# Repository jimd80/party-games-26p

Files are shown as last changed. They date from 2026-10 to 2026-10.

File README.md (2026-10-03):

# 26 Player party game setup

Up to 26 senders
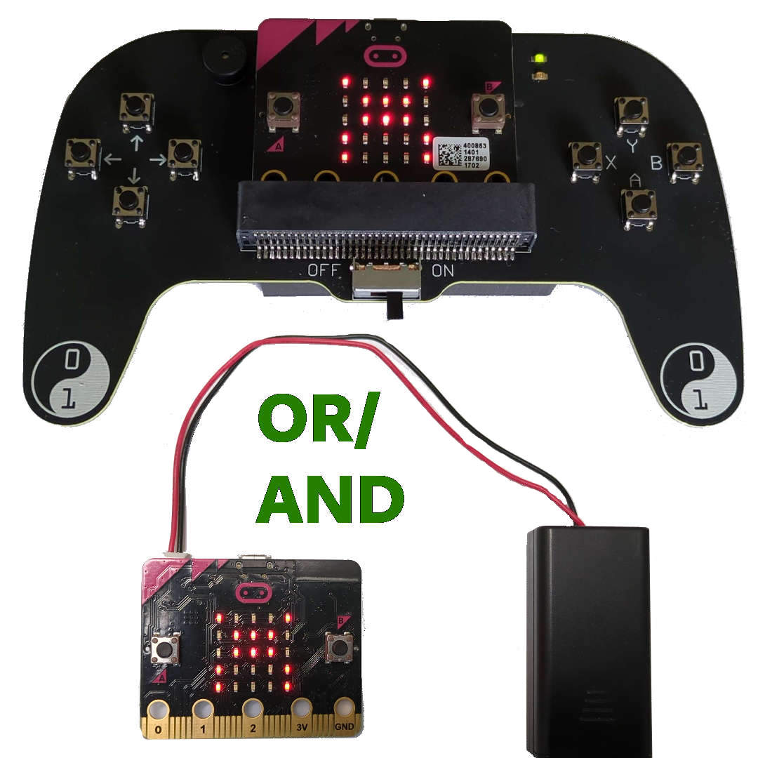
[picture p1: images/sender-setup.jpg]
Sender setup

go to a single receiver
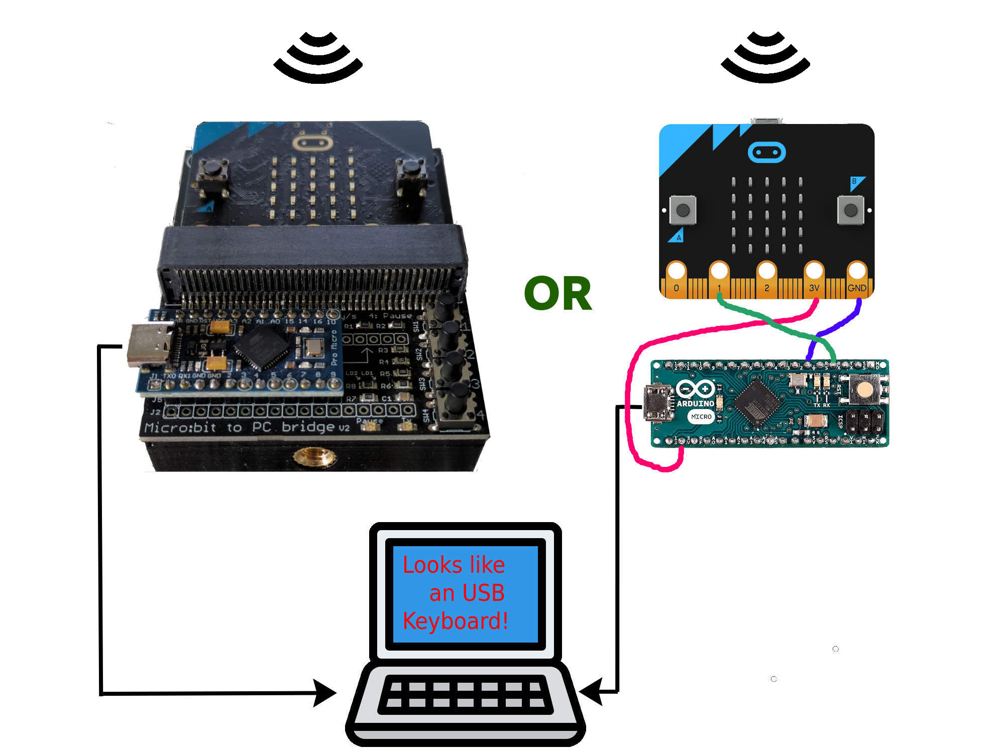
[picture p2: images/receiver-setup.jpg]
Receiver setup


Sending keys A–Z for 26 players.

## The concept
Up to 26 micro:bits act as wireless game controllers. One micro:bit is used as a receiver. Each time a player presses a button, the receiver micro:bit sends a character (A–Z) to the serial port of the Arduino. The Arduino acts as a virtual keyboard for the PC and passes the player's keystrokes as a–z keypresses (player 1 = a, player 2 = b, ..., player 26 = z).

This has some benefits:
- No drivers required; works on any PC, Mac, Chromebook, tablet, etc.
- Games can be developed without the hardware; just use the keyboard `a`–`z` keys to test!
- Easy to develop!

## Setup
Of course you'll need games to play. Check out [games-examples](games-examples/README.md) for a guide on how to write games or directly try the examples.

### The sender
For the sender you have 2 options:
- A micro:bit with a battery box
- Or build the [game controller](https://github.com/jimd80/pxt-coderdojo-controller)

Load [microbit-GameController-v25.12.hex](sender-microbit-src/microbit-GameController-v25.12.hex) from [sender-microbit-src](sender-microbit-src/README.md) into each sender micro:bit using [MakeCode](https://makecode.microbit.org/#editor) or drag it to the `MICROBIT` folder in your file manager.

### The receiver
Get an Arduino Micro, or the Pro Micro clone. Flash [receiver-arduino-v25.7.hex](receiver-arduino-src/release/receiver-arduino-v25.7.hex) from [receiver-arduino-src](receiver-arduino-src/README.md) into the Arduino.

Get a dedicated micro:bit to use as a receiver. Flash [microbit-GameReceiver-v26.3.hex](receiver-microbit-src/microbit-GameReceiver-v26.3.hex) from [receiver-microbit-src](receiver-microbit-src/README.md) into the receiver micro:bit.

Connect the Arduino and micro:bit with 3 wires, as described in [receiver-arduino-src](receiver-arduino-src/README.md).

Alternatively, build the receiver PCB as described in [receiver-pcb](receiver-pcb/README.md).

## How to play
There are plenty of modes to use this setup. We'll go from easy to advanced.

### Quick 26 player
The easiest and fastest setup to play a multiplayer game.

**Senders**: Players just need to turn on their micro:bit. A `?` will appear shortly and a letter is auto-assigned. Button A is the action key to play.

**Receiver**: Plug in the receiver. `26` will appear briefly on the screen. Press button B until `A` (**A**uto-assign) appears and press button A to confirm.

### Personalized 26 player
The controllers are personalized. Give each player a secret code they need to enter into their micro:bit in order for their predefined letter to appear. If managed well, games can keep a preset list of the players' names to show in-game names of the players. The list of "secret codes" can be found in [sender-microbit-src](sender-microbit-src/README.md).

**Senders**: After a player has powered up their micro:bit, a `?` will appear. Now they need to input their code by pressing A and B alternately. For example, if a code is 4567, then A needs to be pressed 4 times, B 5 times, A 6 times, and B 7 times. After this, their assigned letter will appear on the screen.

**Receiver**: Just plug in the receiver; the default mode will just work.

### Programming challenge 26 player
For an extended experience, you can let the players program their micro:bit by themselves with MakeCode blocks.

**Senders**: Let the players create the code as shown in [sender-microbit-src](sender-microbit-src/README.md) (replacing 9999 with their personal code).

**Receiver**: Just plug in the receiver; the default mode will just work.

### 8 button mode 26 player
Games can be advanced to enable all 8 buttons from each player's controller. In this mode, the game not only needs to look at the letter that was pressed, but also at the preceding number, which indicates the button. Each button press from a player is sent as 2 keystrokes, like `5c` = button 5 for player c. More information can be found in [games-examples](games-examples/README.md).

This mode only works if you have both the [game controller](https://github.com/jimd80/pxt-coderdojo-controller) and [receiver PCB](receiver-pcb/README.md).

**Senders**: Same setup as **Quick 26 player** or **Personalized 26 player**.

**Receiver**: Plug in the receiver. Long-press button 4 on the receiver PCB. The green LED will turn on to indicate multi-button mode.

### 8 button mode 4 player
Another way of enabling all 8 buttons per player is limiting the maximum player count to 4. In this way, all 32 keys (8 x 4) can be mapped to a single key on the keyboard, making game programming much easier than the 8-button 26-player mode above.

This mode only works if you have the [game controller](https://github.com/jimd80/pxt-coderdojo-controller).

**Senders**: Power on the micro:bit so `?` appears. Hold A+B until I, II, III, or IIII shows up on the screen to choose player 1–4.

**Receiver**: Plug in the receiver. Press button A until `4` shows up on the screen. The first row of 4 LEDs shows the online status of controllers 1–4.

### Micro:bit project mode
This mode is not to be used with the receiver, but with another custom-programmed micro:bit controlling their own hardware project. More info in the [Remote controlled car exercise](https://drive.google.com/file/d/1tmhRcf0qA-TUM9EA2VIr5EyiVHkkNPFD/view?usp=sharing) (in Dutch).

**Sender**: Power on the micro:bit so `?` appears. Hold A+B until 1, 2, 3, 4, 5, 6, 7, or 8 appears.

**Receiver**: This is a custom program controlling hardware with the game controller.

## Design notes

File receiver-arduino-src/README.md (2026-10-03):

# Micro:bit to PC interface
This project will allow you to connect a micro:bit to an Arduino Micro (or a Pro Micro clone) and connect the Arduino to a computer via USB. The computer will recognize the Arduino as a native keyboard. No drivers required!

The Arduino will translate serial data from the micro:bit into USB KeyDown/KeyUp events.

## Arduino build instructions
The project can be built using VS Code with the PlatformIO add-on. Alternatively, `src/main.cpp` can be renamed to `.ino` if you are using the Arduino IDE. You will need to add the external library `arduino-libraries/Keyboard` manually.

You can tweak the constants `PLAYER_DELAY_MS`, `KEYPRESS_MIN_TIME_MS`, `KEYPRESS_MAX_TIME_MS`, and `MAX_KEYS_SAME_TIME`, but it is strongly advised to leave them as-is. These values were carefully chosen to meet most types of games (either high-volume clicker games or time-accurate "shooting" games).

Keep in mind that 26 controllers will generate a lot of keystrokes! The software is designed to handle a throughput of 26 controllers, each clicking 10 times/second, which is about the human limit of pressing a micro:bit pushbutton. The USB protocol also has a limit of 6 keyboard keys pressed at the same time. Therefore, the minimum time between a KeyDown and KeyUp event is set to 20 ms. This allows a total throughput of 300 keystrokes per second, which is about 11.5 clicks per second per controller.

The time before the same key can be sent again is set to 50 ms. This prevents cheating and buffer backlog floods. To protect even more from cheating, when the same key is received within 50 ms, the wait time will restart. This prevents a cheater from sending on a 30 ms interval, which would still result in a 60 ms interval. That is still faster than the human limit.

The keyboard layout is set to Belgium or France (AZERTY). If you use another keyboard layout, please change `KB_LAYOUT`.

## Flashing
No need to compile by yourself if you're okay with the default settings (like AZERTY and key press delays).

Use Arduino IDE or VS Code with PlatformIO to directly flash the hex file you can find in the `release` folder.

## Use without PCB

3 Wires are needed to connect the micro:bit to an Arduino Micro:

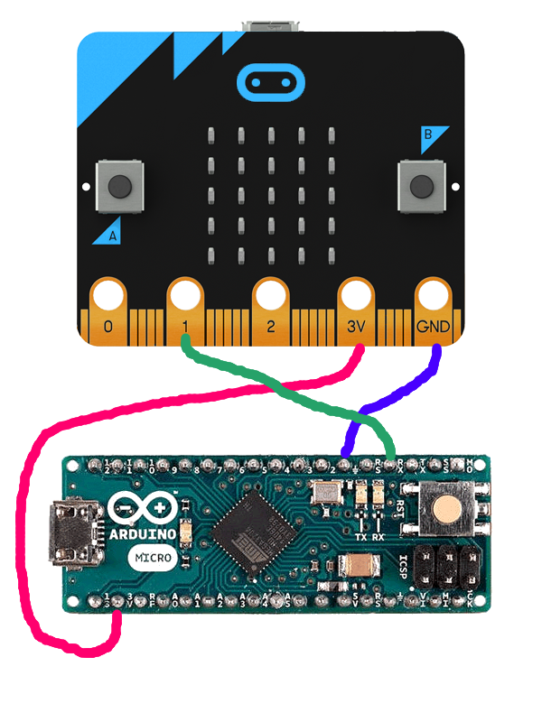
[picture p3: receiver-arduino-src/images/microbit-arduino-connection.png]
Arduino connection


Alternatively, for a Pro Micro the wiring is different:

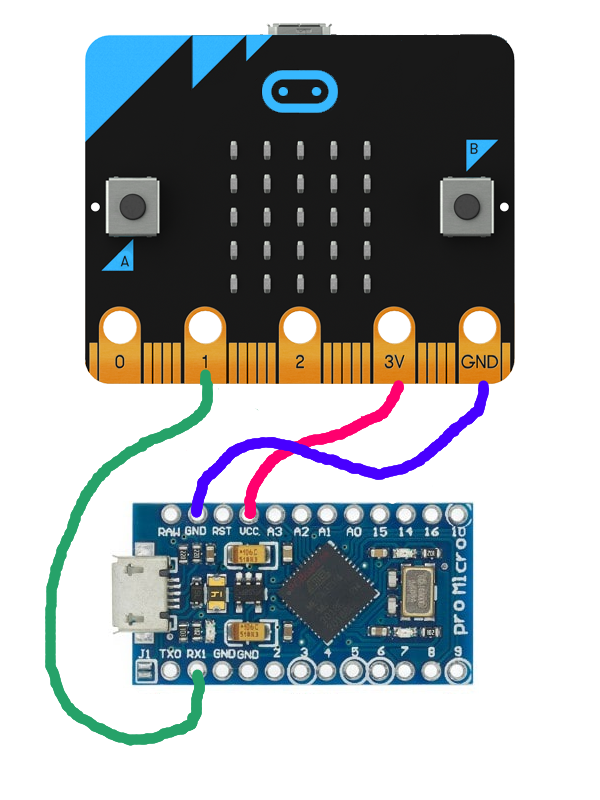
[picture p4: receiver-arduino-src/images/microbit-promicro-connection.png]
Pro Micro connection


## Extra features when using the PCB

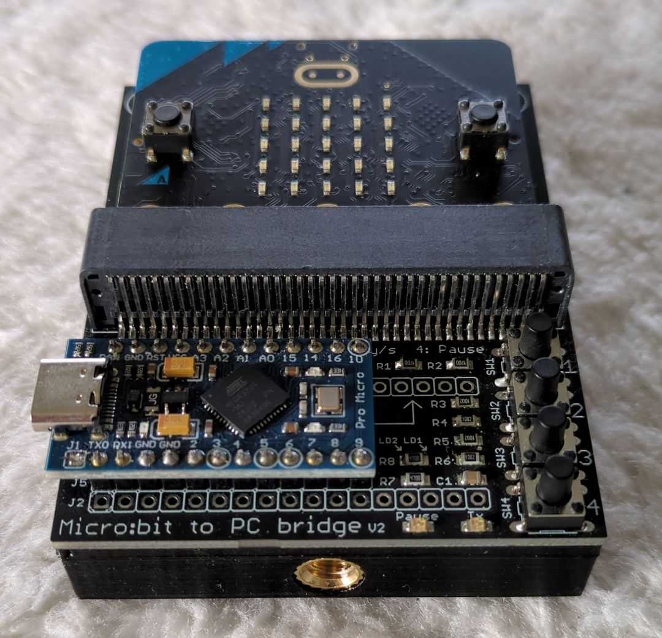
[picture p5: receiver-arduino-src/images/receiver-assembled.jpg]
Receiver


When using the software with our custom PCB, extra features become available:

- **Button 1 short press**: sends a keypress for the letter `a` to the computer. It is used to test if the keyboard is recognized by the computer.
- **Button 1 long press**: switches between AZERTY and QWERTY mode. If the above test sends a `q` to the computer instead of an `a`, switch modes.
- **Button 2 press**: rapidly sends all `a` to `z` keypresses with 5 milliseconds in between (26 keys in 130 ms total).
- **Button 3 press**: rapidly sends all `a` to `z` keypresses 10 times with 3 milliseconds in between (260 keys in 780 ms total).
- **Button 4 short press**: toggles mute mode. The red LED will be on to show that no keypresses are currently passed through.
- **Button 4 long press**: toggles between 1-button and 8-button mode. In 8-button mode, every player can use all 8 buttons on the game controller. Letters are prefixed by numbers to indicate which button is pressed.

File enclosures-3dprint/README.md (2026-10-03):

## Micro:bit, cable, and battery box holder

Print `Microbit case.stl` or choose a custom number of rows / columns by editing `Microbit case.scad` for compact storage.

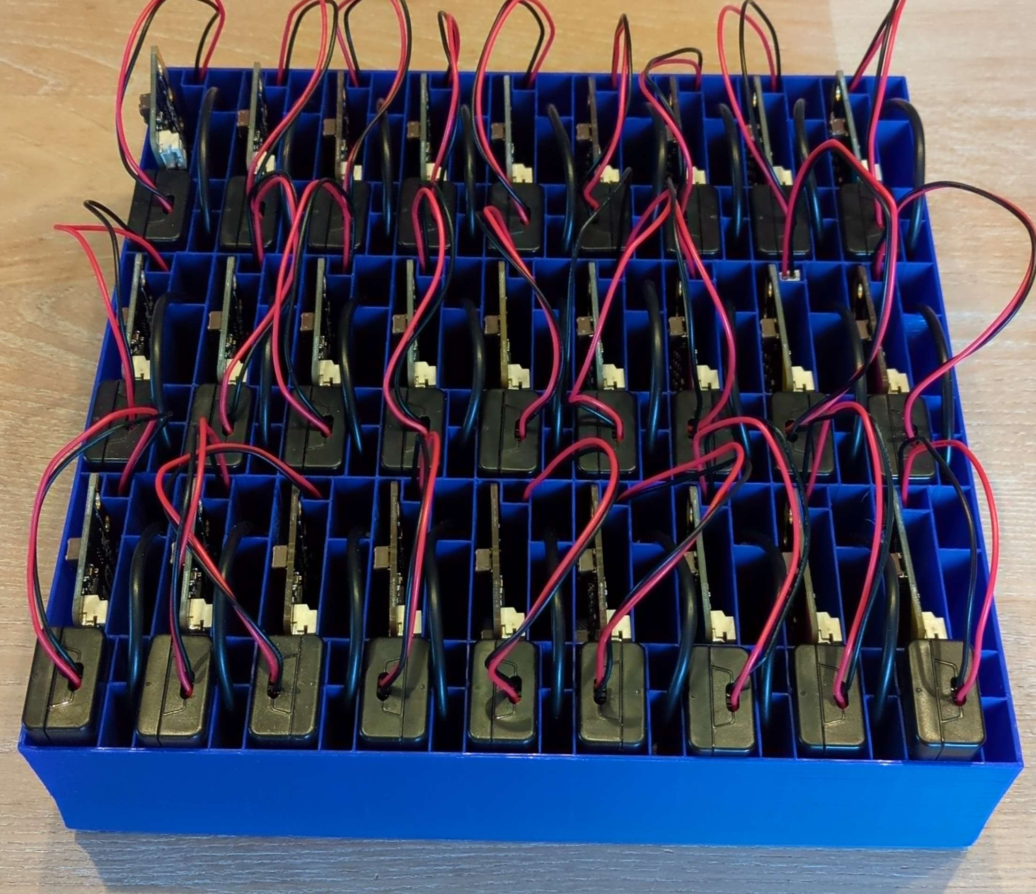
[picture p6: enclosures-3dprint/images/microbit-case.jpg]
Microbit case


## Game controller box

Controller box STL files are available to print a storage case for the game controllers. You can adjust the `Controler box.scad` file for any number of controllers.

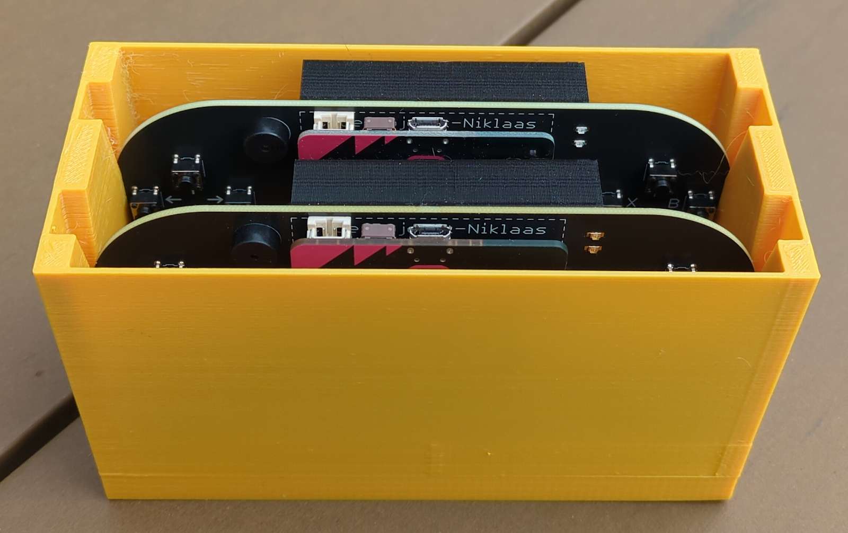
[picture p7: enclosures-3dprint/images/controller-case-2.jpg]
Controller case


Combine several holders so they will fit in a handy toolbox.

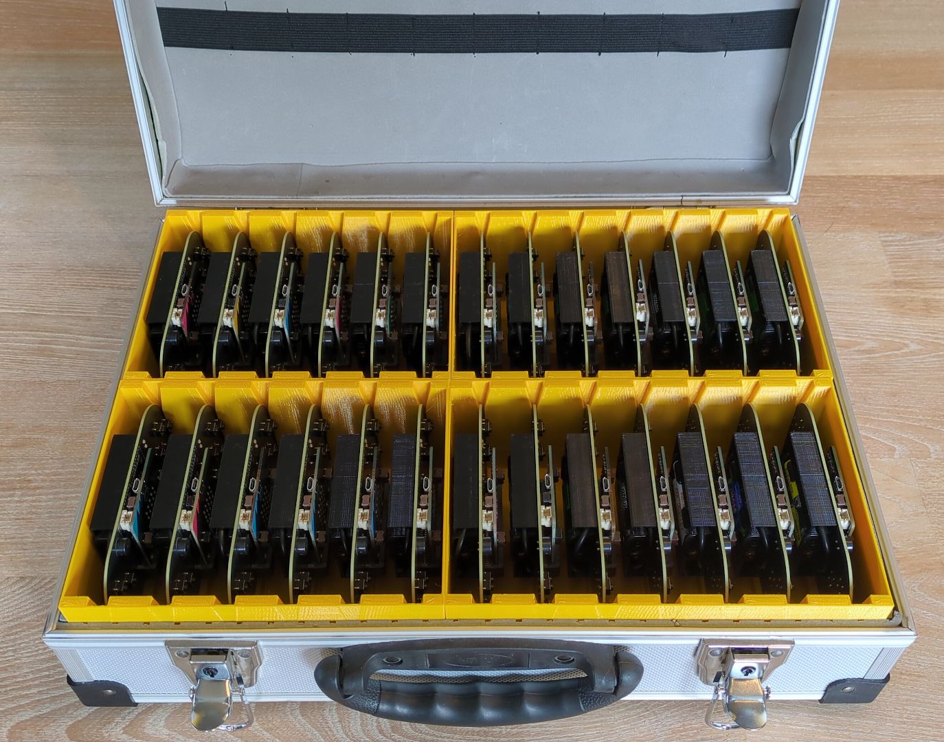
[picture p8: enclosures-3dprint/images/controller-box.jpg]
Controller box


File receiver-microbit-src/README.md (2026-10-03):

## Micro:bit 26p games receiver

This program works together with the Arduino. The micro:bit receives radio signals from the sender and sends the pressed key codes over a serial port to the Arduino, which then translates this into USB keyboard events.

Flash [microbit-GameReceiver-v26.3.hex](microbit-GameReceiver-v26.3.hex) into the micro:bit (which is connected to the Arduino) with [MakeCode](https://makecode.microbit.org/#editor) or drag it to the `MICROBIT` folder in your file manager.

## Button and LED usage

Button A toggles the mode between 26-player mode <-> Pause <-> 4-player mode.
Button B toggles through options (depending on the current mode). Press A to confirm the option.

### Modes (select with button A):
- **26-player mode**: Sends keys `a`–`z` to the computer. When a player keeps pressing their button, the key is repeated at a 300 ms interval. The 25 LEDs on the micro:bit show the online status of the a–y players.
- **4-player mode**: Sends keys from 4 controllers according to a specific mapping (see below). The LEDs on the micro:bit show a `4`, and the first 4 LEDs (top row) show the online status of the 4 controllers.
- **Pause mode**: Shows `||` on the LED screen. Keys are not sent to the computer. The option menu (Button B) has several test/debug options.

### Options (select with button B):
Not all options are available for each mode!
- **R**: Recover the player letter when a controller is turned off and on again so the player does not have to enter their code again.
- **A**: Auto-assign A–Z to controllers after power-up. Skip player numbers that were previously configured on other controllers. Also recover on power loss.
- **X**: Letter assignment A–Z is done by pressing the X button on the game controller. This allows setting a certain player order.
- **N**: Controllers do not remember their player letter and are not auto-assigned.
- **T**: Request 50 x 100 ms button A presses from 26p-configured controllers.
- **V**: Show version.
- **R**: Reset.
- **T**: Request all controllers in startup mode (showing a `?`) to send simulated button presses.
- **D**: Debug mode, custom test.
- **<**: Back without selecting this option.

## 4 player mode key mapping
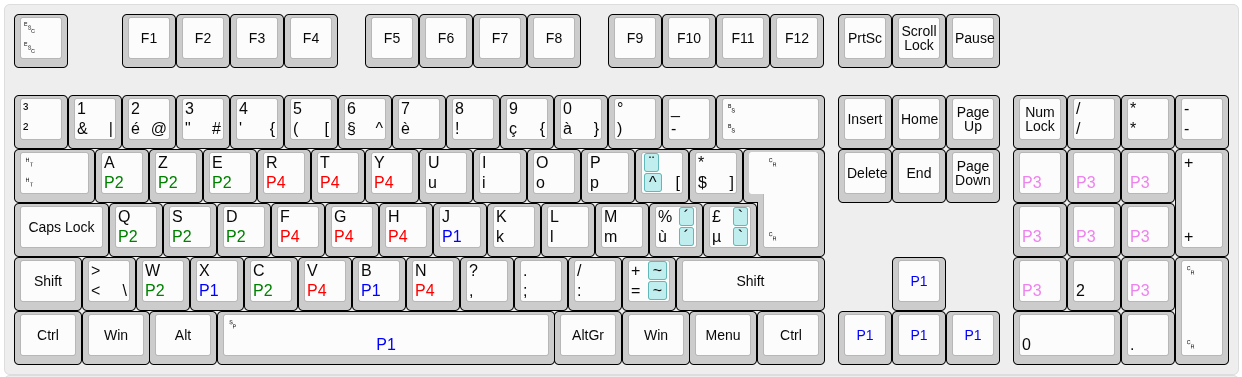
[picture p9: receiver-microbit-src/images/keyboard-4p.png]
4p mode keyboard mapping


## Version history
`microbit-GameReceiver-v26.3.hex`:
- Settings menu also acts as pause, new icon ||
- Button A now toggles mode26 <-> pause/settings <-fastpress-> mode4
- 4p mode defaults to X function (press X to assign)

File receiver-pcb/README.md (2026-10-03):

## Hardware building guide
The (empty) PCB can be easily manufactured by any PCB company, for example JLCPCB which is known as the cheapest. The (tripod) holder can be 3D printed with any 3D printer, for example the affordable Creality Ender V2 or V3.

Other parts can be ordered at various electronics suppliers such as LCSC, AliExpress, DigiKey, Farnell, etc. The most difficult part to source will be the micro:bit EDGE connector. This needs to be the horizontal SMD version, and needs to look exactly like this:

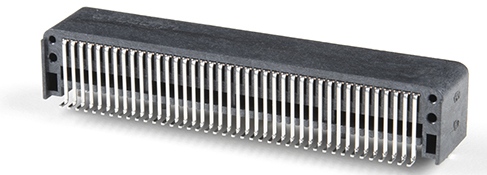
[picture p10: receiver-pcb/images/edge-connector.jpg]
EDGE Connector


Soldering can be done with (lead-free) solder paste and a reflow oven, or if you are a bit handy it can also be done with a classic soldering iron, lead-free solder wire, and some flux. In that case, it will be handy to have something to keep the parts in place while soldering, such as a screwdriver.

## Tools needed

You'll need some tools and skills to build this project:
- A soldering iron and lead-free solder wire
- Optionally, a reflow oven OR a hot-air gun. Using this option you'll also need lead-free solder paste, such as Chipquik TS391SNL
- Recommended: Flux, such as Chipquik SMD291NL

## Step 1: Ordering the parts
Collect these parts:

Part number      |Reference	            |Description                      |Qty|Price|Order link example|
:----------------|:---------------------|:--------------------------------|--:|----:|:-----------------|
R1, R2, R7, R8   |Res 470R SMD0805      |Resistor 470R / 1% / 0.1W / 0805 |  4|€0.02|[LCSC](https://www.lcsc.com/product-detail/Chip-Resistor-Surface-Mount_YAGEO-RC0805FR-07470RL_C114564.html)|
R3, R4, R5, R6   |Res 10K SMD0805       |Resistor 10K / 1% / 0.1W / 0805  |  4|€0.06||
C1               |Cap 100nF SMD0805     |Capacitor 100nF / 50V / SMD 0805 |  1|€0.04||
SW1,2,3,4        |Pushbutton 6x6x5mm    |Pushbutton (on)-off 6x6x5mm      |  4|€0.05|[AliExpress](https://www.aliexpress.com/item/1005001897291190.html)|
J1, J2           |Pinhdr 1x17           |Pinheader 17p 2.54mm             |  2|€0.04||
J3               |Edge connector hor SMD|Micro:bit edge connector SMD/hor |  1|€0.85|[AliExpress](https://www.aliexpress.com/item/1005006206948907.html)|
J4, J5           |Pinhdr 1x12           |Pinheader 12p 2.54mm             |  2|€0.04||
LD1              |LED Green SMD0805     |Led Green SMD 0805               |  1|€0.02|[LCSC](https://www.lcsc.com/product-detail/LED-Indication-Discrete_XINGLIGHT-XL-2012UGC_C965815.html)|
LD2              |LED Red SMD0805       |Led Red SMD 0805                 |  1|€0.02|[LCSC](https://www.lcsc.com/product-detail/LED-Indication-Discrete_XINGLIGHT-XL-2012SURC_C965812.html)|
Other            |Screw M3x10           |Screw M3x10 flat head            |  3|€0.04||
Other            |1/4-20 UNC nut        |Tripod mounting insert nut       |  2|€0.10|[AliExpress](https://nl.aliexpress.com/item/1005008462611857.html)|

## Step 2: Ordering the PCB
The PCB (without components) needs to be manufactured by a company. Here are the instructions for JLCPCB:
- Create a zip file from the `Gerber-JLCPCB` folder
- Go to https://jlcpcb.com
- Choose "Add Gerber file" and upload the zip file you created
- Select your desired quantity (the more you order, the cheaper per board)
- Change PCB Color to Black
- Change Surface Finish to LeadFree HASL (if RoHS is required in your country; this is always the case for the EU)
- Choose Mark on PCB: Remove Mark  
All other options are okay by default. Complete the order process.

## Step 3: Solder the edge connector
The edge connector is preferably soldered with a soldering iron, as it is not clear if it can withstand the 240 °C hot air required for lead-free soldering. Use extra flux to create smooth joints. After soldering, remove the flux with isopropyl alcohol.

## Step 4: Solder the SMD parts
In the bill of materials above you'll find which parts belong to which part numbers printed on the PCB (such as R1, C1, ...). Only for the two LEDs does the direction of the part (polarity) matter. There is usually an indicator (like a small green dot or a line) that should point in the direction of the arrow on the PCB.

Soldering SMD parts can be done in several ways; there are many tutorials online such as https://www.youtube.com/watch?v=hoLf8gvvXXU or https://www.youtube.com/watch?v=fYInlAmPnGo.

## Step 5: Solder the pin headers and Arduino / Pro Micro
When using an Arduino Micro, solder the J1 and J2 pin headers onto the PCB. Next, place the Arduino (with the USB connector pointing to the left) over the pin headers and solder it.

When using a Pro Micro, solder J4 and J5 instead.

Finished PCB

## Step 6: Program the Arduino / Pro Micro

Flash the hex file found in `receiver-arduino-src/release` to the Arduino / Pro Micro (using Arduino IDE or VS Code with PlatformIO).

Check if it works by unplugging and plugging the Arduino back in. Open Notepad and press button 1; an `a` (or `q`) keypress should be registered on each press.

## Step 7: 3D print the holder
This step is not required if you just want to put the PCB on a table during use:
- Download [party-games-receiver.stl](CAD-Files/party-games-receiver.stl)
- Process the file in your slicer. Recommended layer height is 0.2 mm and recommended speed is 50 mm/s.
- Print it, preferably with black PETG, as this is more fire-resistant than PLA or ABS.
- Use a soldering iron to hot-press-insert the tripod mounting nuts into the holder.

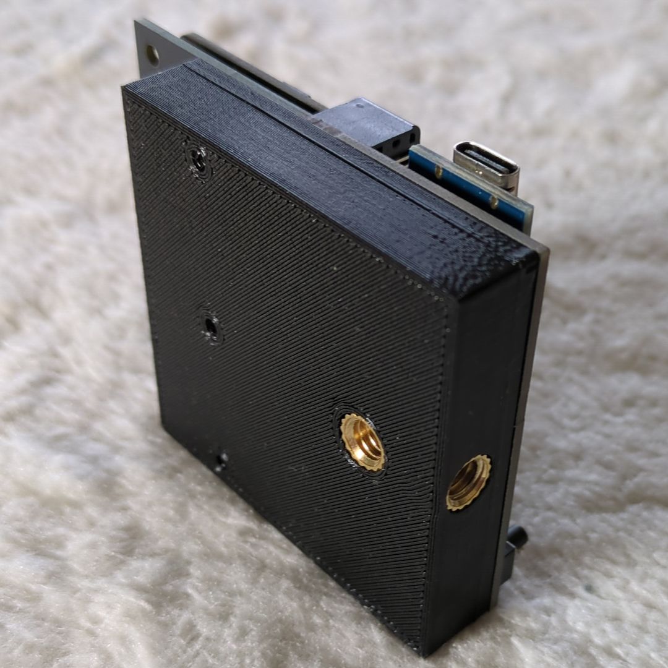
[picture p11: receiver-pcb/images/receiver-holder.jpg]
Receiver holder


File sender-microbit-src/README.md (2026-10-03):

# 26p party game micro:bit controller

## The basic version (for coding exercise)

You can make the gaming experience more educational by letting the participants program their game controller by themselves!

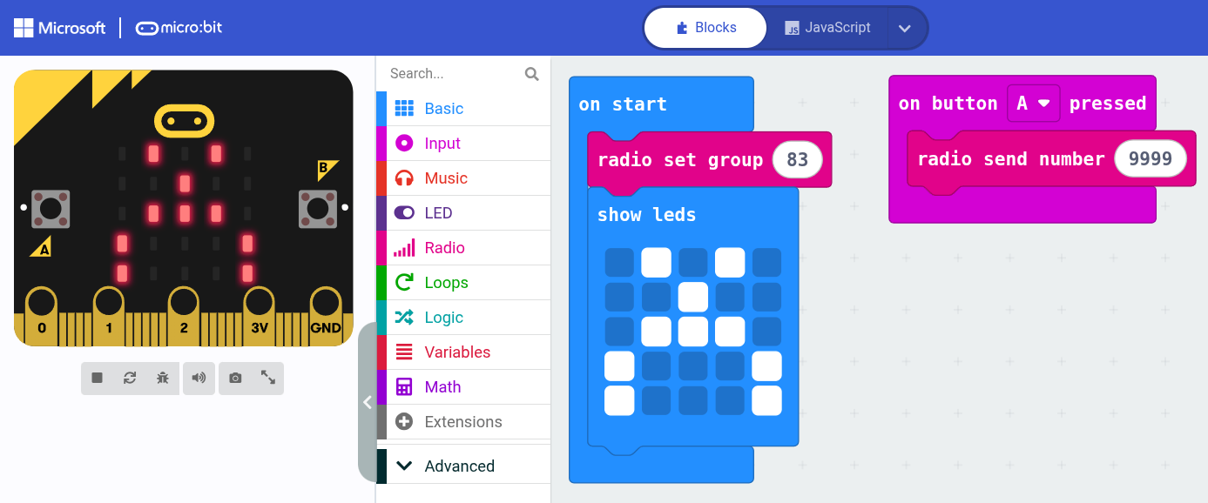
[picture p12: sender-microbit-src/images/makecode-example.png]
MakeCode example


The code above is all that is needed to have a simple 1-button game controller.

Give each participant a "secret 4-digit code" to identify their controller with a letter A–Z. Replace `9999` in the example with this code. Leave the radio channel at 83 for all players.

We chose not to send the letters A–Z directly over the radio, as this could lead to cheating or mistakes. A 4-digit code will simply work or not.

| Key Code | | A 1461 | B 2581 |
|:---|:---|:---|:---|
| C 3327 | D 4374 | E 5717 | F 6459 |
| G 7693 | H 8352 | I 9167 | J 1986 |
| K 2118 | L 3634 | M 4773 | N 5668 |
| O 6531 | P 7922 | Q 8726 | R 9628 |
| S 1399 | T 2951 | U 3848 | V 4124 |
| W 7823 | X 8854 | Y 4975 | Z 8942 |

## The standard version (for versatile and quick setup)

Usually there is not enough time for everyone to program their micro:bit. For a quick game setup, this prebuilt program can be used, which supports all kinds of advanced modes.

Flash all micro:bits that will be used as senders with the latest [microbit-GameController-v25.12.hex](microbit-GameController-v25.12.hex) using MakeCode or drag and drop into your file manager.

## Technical details (how it works)

### 26 player mode

The player enters their "secret" PlayerCode using the A and B buttons; this maps to A–Z. Used for PC multiplayer games where each player maps to keyboard A–Z (optionally prefixed with ButtonNr).

- Each button press is sent as number `[ButtonNr][PlayerCode]` to Channel 83. Example: 41986 (J presses Left). ButtonNr: A=0, B=5, X=7, Y=9, U=8, D=2, L=4, R=6.
- When keeping key(s) pressed, the initial key being held down is repeated every 250 ms (actually 240–265 ms) as number `[1][ButtonNr][PlayerCode]`. Example: 141986 (J is holding Left).
- A keepalive message is sent every 5 s as `alive[PlayerCode]=[serial]`. Example: `alive1986=123456789` (Player J has been idle for 5 seconds or longer).

### 4 player mode

To enter this mode, hold A+B and release on I, II, III, or IIII. Used for PC multiplayer games up to 4 players with less complexity than 26-player games. All 8 buttons are available as single key presses.

- KeyUp/KeyDown events are passed through to the PC for more game features (like moving as long as a key is pressed).
- Current keys held down are repeatedly sent to CH83 as a string, prefixed by player number. Examples: '1A', '1ABXYUDLR', '8L', '8'.
- Any change in key up or down sends the current keys-down string 4 times (40 ms) to avoid stuck keys on missed messages.

### Control mode

This mode is entered on startup. A `?` is shown on screen. Exited when entering 4-, 8-, or 26-player mode.

- Every second, the controller sends key/value `hello=[serial]` to Channel 83 to announce itself. Another controller can then instruct it to enter a mode, for example to recover mode from power loss.
- When the controller enters a mode, it sends `enter[modeNr]=[serial]` 4 times. `modeNr` is 1–26 for 26-player mode, 101–108 for 8-player mode, and 201–204 for 4-player mode.
- When the controller receives `set[modeNr]=[serial]`, it will enter that mode and leave control mode. It sends `enter[modeNr]=[serial]` 4 times.
- When the controller receives `t50s[gamecode]=[serial]`, it will send the gamecode 50 times every 100 ms. When there is no gamecode, only the controllers in 26-player mode will send their gamecode (`t50f` for multikey).
- When a player presses X, Y, U, D, L, or R, a key/value of `press[button]=[serial]` is sent to CH83. This allows advanced control in assigning a mode on player request.
- When a player presses U+D+Y+A, the controller shows the version.

### micro:bit mode

Hold A+B and release on 1–8. Used for micro:bit projects like driving a car or handling a crane.

- Current keys held down are repeatedly sent to CH1–8 as a string, prefixed by player number. Examples: '1A', '1ABXYUDLR', '8L', '8'.
- Holding Y additionally sends the gyro position every 100 ms as a number, YYXX from 0000 to 9999.
- Any change in key up or down sends the current keys-down string 4 times (40 ms) to avoid stuck keys on missed messages.

### During any mode (except micro:bit mode)

- When a controller receives `reset=[serial]`, it will reset.
- When a controller receives `imgXXXXX=[serial]`, it will draw an image (1 letter = 1 row, showing bits of charcode - 60).

## Version history

`microbit-GameController-v25.12.hex`:

- Multiple keys pressed: repeat first pressed key instead of last.

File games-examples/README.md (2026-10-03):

# How to develop a 26p game?

Game development is easy: each player has 1 action key. Key `a` for player 1, `b` for player 2, etc.

The limitation here is that holding keys is not supported. If a player holds down a button for 1 second, there will be no KeyDown/KeyUp events 1 second apart. Instead, the key will be repeated as long as it is pressed at a 300 ms interval.

## 26p Scratch games

Creating a 26p game in Scratch can be challenging as you don't want to duplicate code 26 times. To avoid this, the use of clones is highly encouraged.

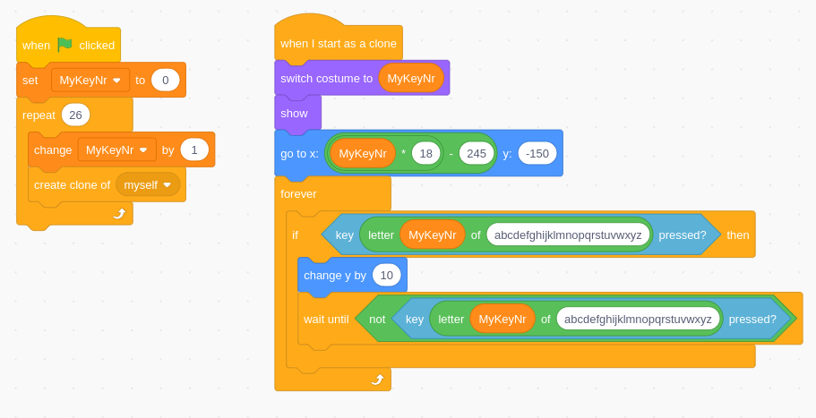
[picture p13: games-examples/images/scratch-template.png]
Scratch template


There is a Scratch guide available (in Dutch):
[Scratch 26p game guide](https://drive.google.com/file/d/1EKSQh_yyUaG9uiFE4w32-fW5PQwD0ZBr/view)

Check out the games we already developed, ready to play! (No hardware needed, just use A–Z on the keyboard!)

[26p scratch games](https://scratch.mit.edu/studios/37038292)

## 26p HTML games

Of course games can be developed in other languages and even vibe-coded with AI. Check them out here:

[26p html games](https://justga.me/?tags=26player)

A vibe-coding guide is available (in Dutch):
[Create 26p games with AI](https://drive.google.com/file/d/1PFyaRbHaIZouSNt_Dz_1HN4087KHPSFB/view)

## 4p games

When using the game controller as the sender, 8 buttons are available for each player. There is a 4p mode available:

- On the receiver micro:bit: Press A until "4" shows up on the screen.
- On the sender micro:bits: Hold A+B until I, II, III or IIII shows up on the screen to choose player 1–4.

In this mode, the 8 keys for each player (P1–P4) are mapped like this:

Also in this mode, long-pressing keys is fully supported just like a normal keyboard.

4p keyboard layout

Creating a game is then just like using a standard keyboard. There is also a Scratch guide available (in Dutch):
[Scratch 4p game guide](https://drive.google.com/file/d/1WkpQUapTLY1sVuhUzJ75bDTOG1CPytpc/view)

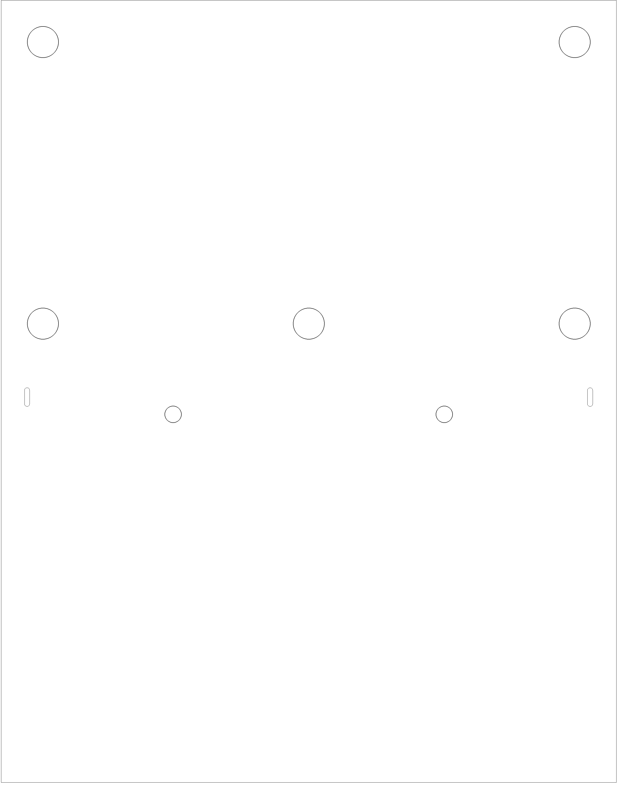
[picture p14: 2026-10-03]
receiver-pcb/CAD-Images/mechanical.png

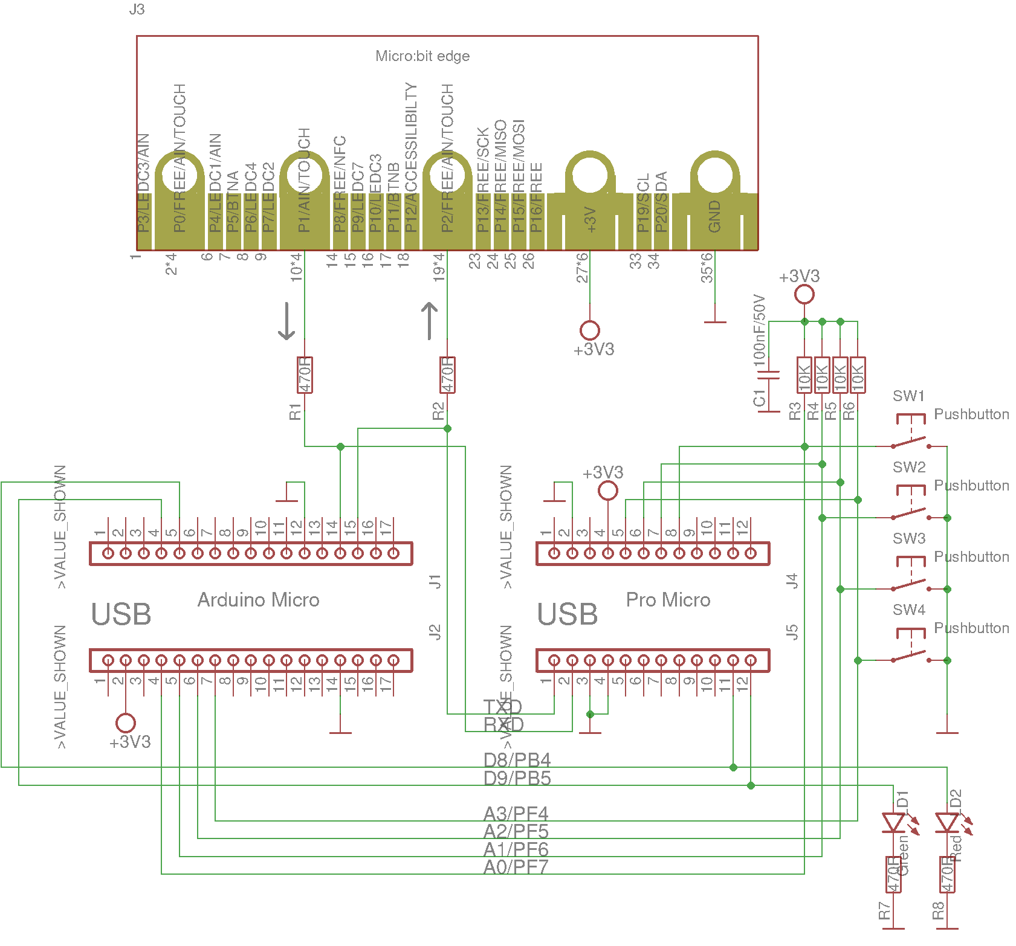
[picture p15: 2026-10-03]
receiver-pcb/CAD-Images/Schematic_sheet_1.png

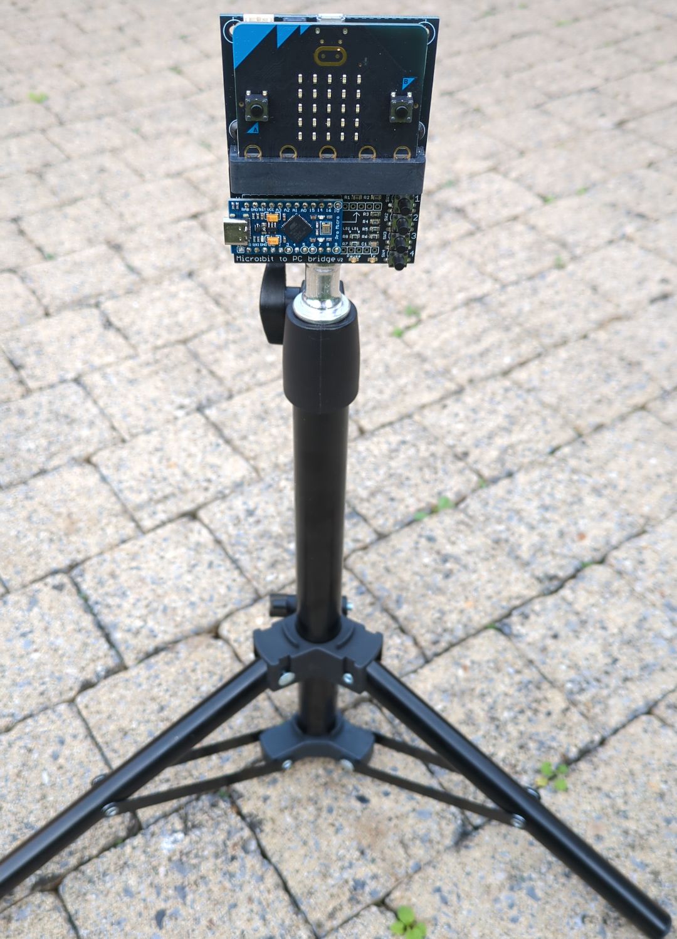
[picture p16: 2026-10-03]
receiver-pcb/images/receiver-stand.jpg

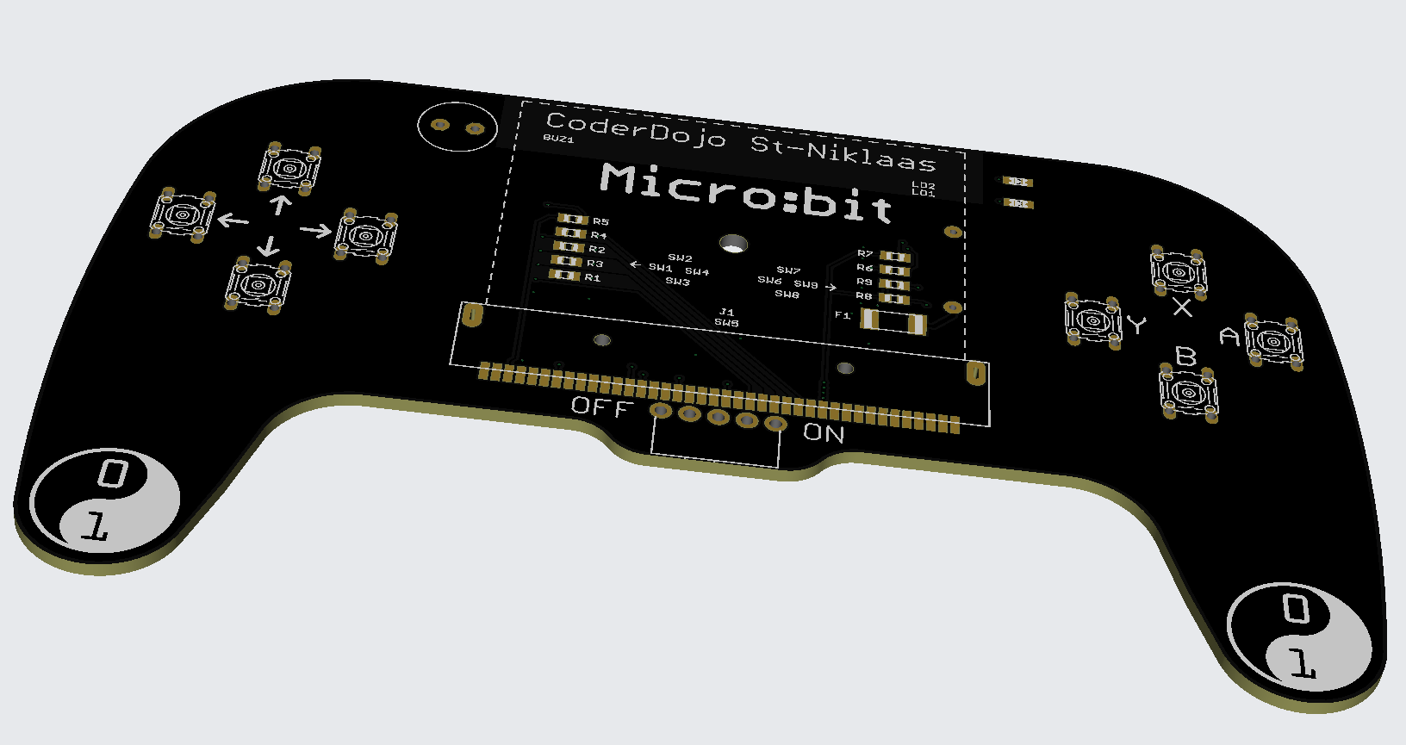
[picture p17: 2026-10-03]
sender-microbit-src/images/Gamecontroller pcb 3d.png

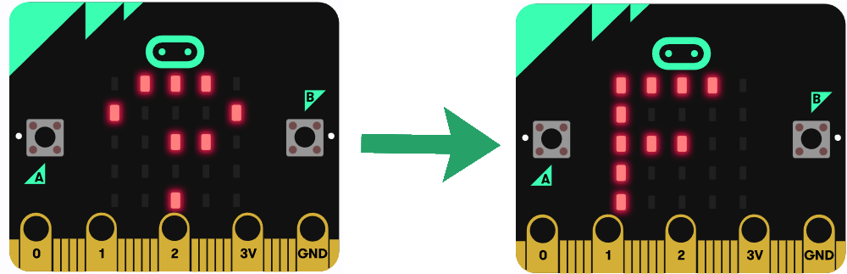
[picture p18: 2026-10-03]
sender-microbit-src/images/Microbit gamecontroller universal.png

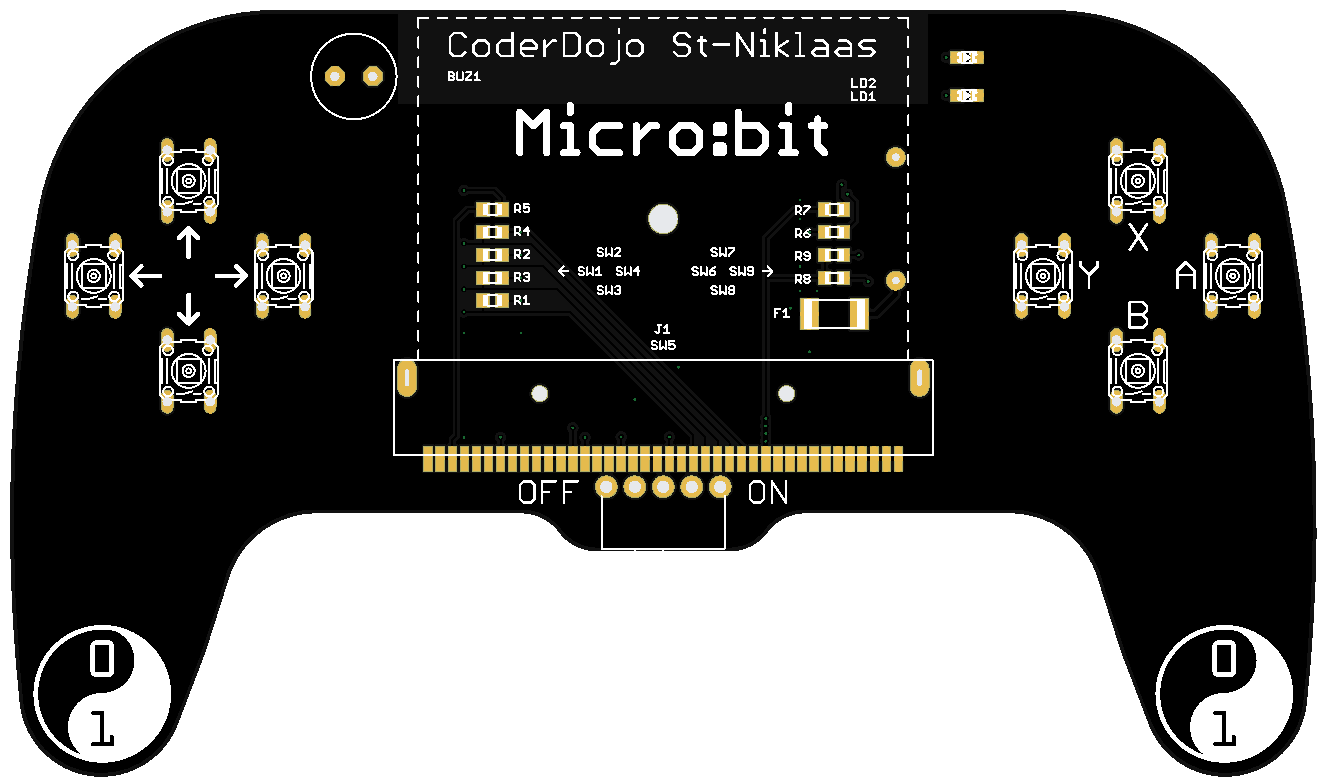
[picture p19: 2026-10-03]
sender-microbit-src/images/Gamecontroller pcb.png

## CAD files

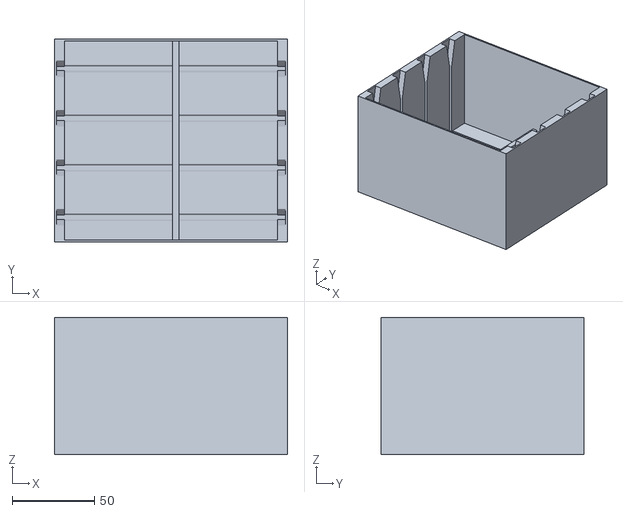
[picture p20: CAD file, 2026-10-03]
enclosures-3dprint/Controller box 4.stl
141.4 x 123.3 x 83.2

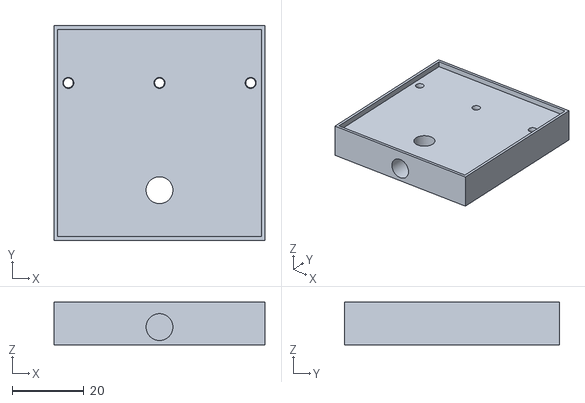
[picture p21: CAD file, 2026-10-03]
receiver-pcb/CAD-Files/party-games-receiver.stl
59.0 x 60.0 x 12.0

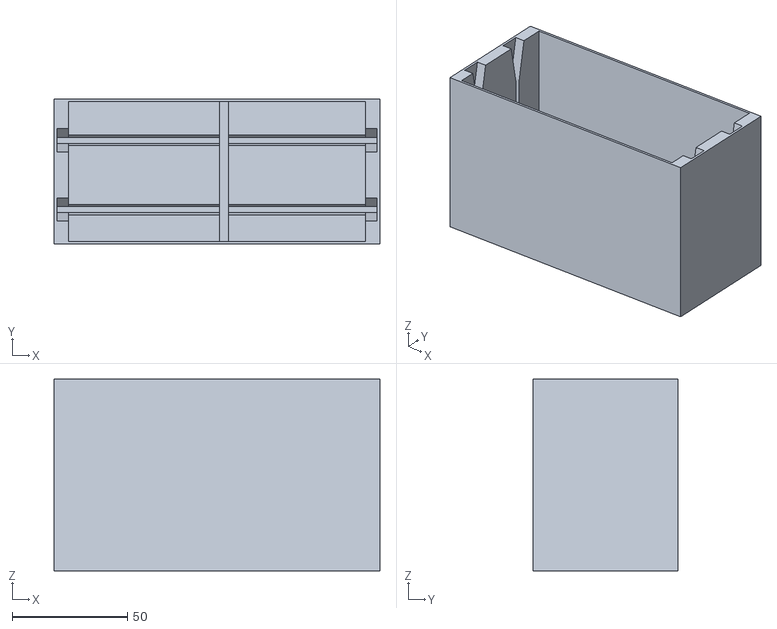
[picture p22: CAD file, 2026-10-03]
enclosures-3dprint/Controller box 2.stl
141.4 x 63.1 x 83.2

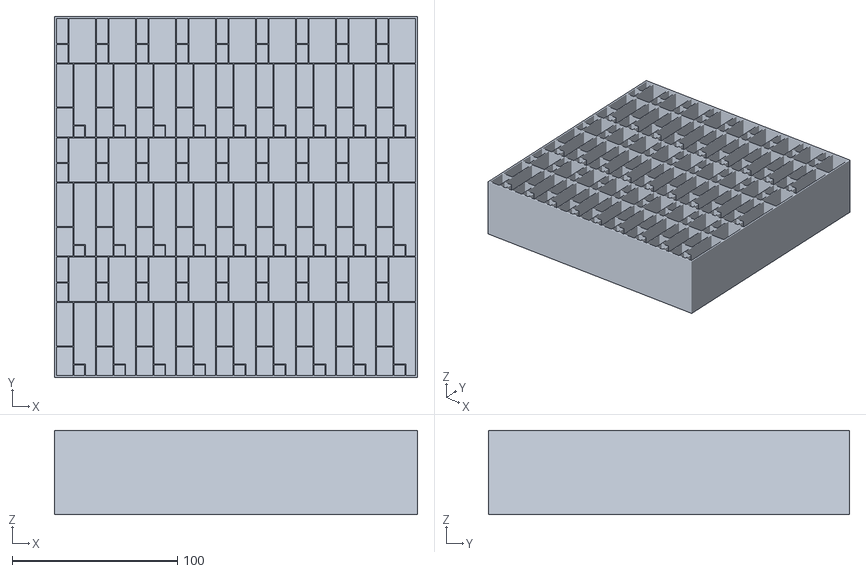
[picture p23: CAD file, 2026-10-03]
enclosures-3dprint/Microbit case.stl
219.6 x 218.4 x 51.0

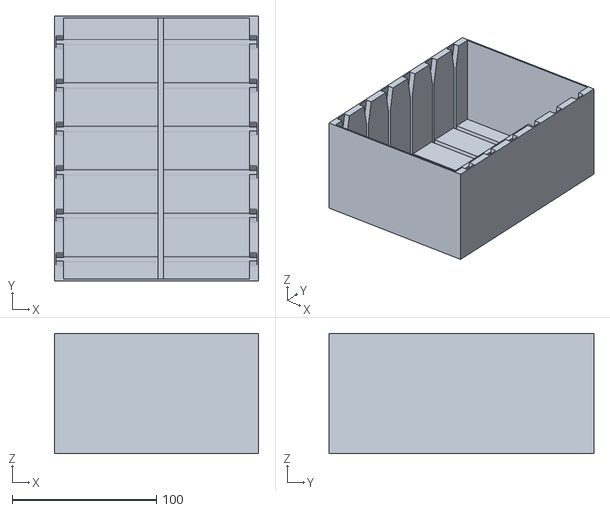
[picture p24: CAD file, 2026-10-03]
enclosures-3dprint/Controller box 6.stl
141.4 x 183.5 x 83.2

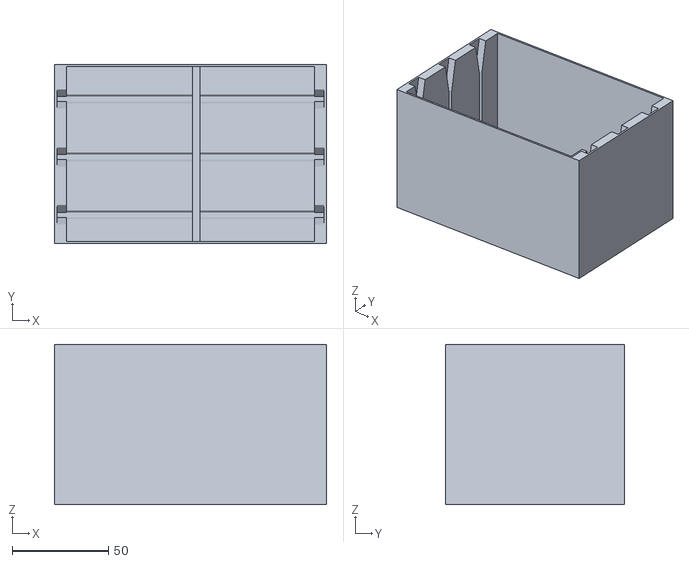
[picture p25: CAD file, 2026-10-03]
enclosures-3dprint/Controller box 3.stl
141.4 x 93.2 x 83.2

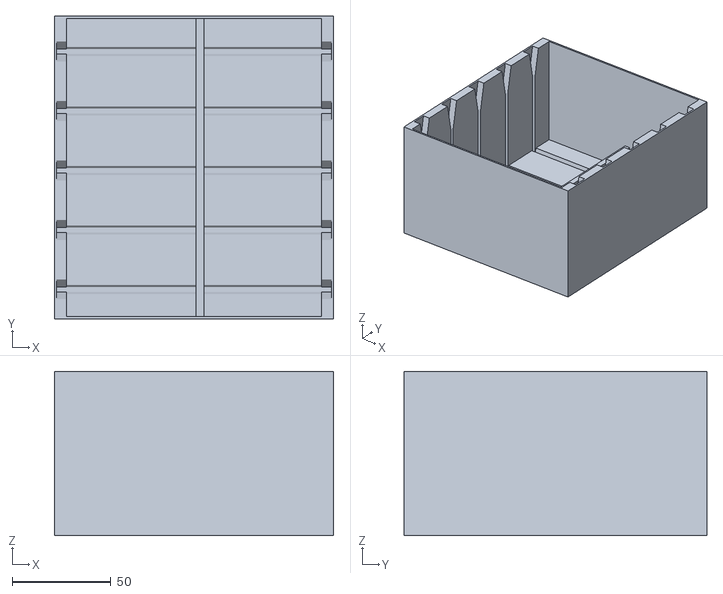
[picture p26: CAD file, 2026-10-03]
enclosures-3dprint/Controller box 5.stl
141.4 x 153.4 x 83.2

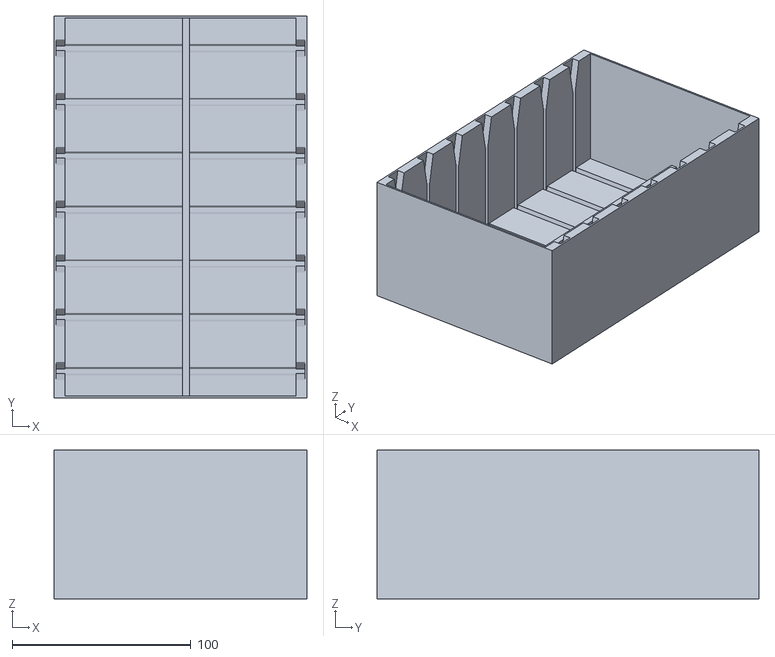
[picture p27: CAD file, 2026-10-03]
enclosures-3dprint/Controller box 7.stl
141.4 x 213.6 x 83.2

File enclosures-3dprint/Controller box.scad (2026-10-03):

use <D2Lib v2.scad>;

// Dimensions in mm
// Ender3 v2: x=224, y=212
// Ender3 v3: x=220, y=220
// battery box: 15.5 x 25.8 x 52.75 conn: 5.6 x 4.2
// microbit: 43.2 x 11 x 51.8
// cable: 60 x 7.2 x 66     16.4x7.2   10x6.2
//
// L: 1.2 + 3x (44.2 + .6 + 26.8) + .6 + 1.2 - .6 = 218.4
// W: 1.2 + 9x (7.2 + .6 + 15.5) + .6 + 1.2 - .6 = 216.9

count = 6;
game_width = 139;
game_height = 82;
game_pcb_thick = 1.6;
game_front_thick = 12;
game_back_thick = 15;

game_switch_h1 = 19;
game_switch_h2 = 23.4;
game_switch_xoff1 = 1;
game_switch_xoff2 = 5;

case_wall = 1.2;
case_bottom = 1.2;

wall_clearance = 1;
game_clearance = 1.5;
insert_margin = 1;

top_sleeve_w = 5;
top_sleeve_insert_w = 10;
top_sleeve_insert_h = 20;

bottom_sleeve_h = 5;
bottom_sleeve_insert_w = game_pcb_thick + insert_margin + 2;

// Init
$fn=$preview ? 20 : 50;
q = .01;
q2 = q*2;

game_thick = game_front_thick + game_pcb_thick + game_back_thick;
game_spacing = game_thick + game_clearance;
total_w = case_wall + game_width + case_wall;
total_l = case_wall + wall_clearance + game_thick * count + game_clearance * (count - 1) + wall_clearance + case_wall;
total_h = case_bottom + game_height;

echo("Total w: ", total_w);
echo("Total l: ", total_l);

difference()
{
    beam_xyz(0, total_w, 0, total_l, 0, total_h);
    beam_xyz(case_wall + top_sleeve_w, total_w - case_wall - top_sleeve_w, case_wall, total_l - case_wall, case_bottom + bottom_sleeve_h, total_h + q);
    
    for (i = [0:count-1])
    {
        // side and bottom cutouts
        margin = insert_margin / 2;
        beam_xyz(case_wall, total_w - case_wall,
        case_wall + wall_clearance + game_front_thick + game_spacing * i - margin,
        case_wall + wall_clearance + game_front_thick + game_spacing * i + game_pcb_thick + margin,
        case_bottom, total_h + q);
        
        // top insert
        dy = (top_sleeve_insert_w - (game_pcb_thick + insert_margin)) / 2;
        beam_xyz_slopedz4(case_wall, total_w - case_wall,
        case_wall + wall_clearance + game_front_thick + game_spacing * i - margin,
        case_wall + wall_clearance + game_front_thick + game_spacing * i + game_pcb_thick + margin,
        total_h - top_sleeve_insert_h, total_h + q,
        0,0,-dy,-dy);
        
        // bottom insert
        dy2 = (bottom_sleeve_insert_w - (game_pcb_thick + insert_margin)) / 2;
        beam_xyz_slopedz4(case_wall + top_sleeve_w, total_w - case_wall - top_sleeve_w,
        case_wall + wall_clearance + game_front_thick + game_spacing * i - margin,
        case_wall + wall_clearance + game_front_thick + game_spacing * i + game_pcb_thick + margin,
        case_bottom, case_bottom + bottom_sleeve_h + q,
        0,0,-dy2,-dy2);
    }
}

beam_xyz(total_w / 2 + game_switch_xoff1, total_w / 2 + game_switch_xoff2, 0, total_l, 0, case_bottom + game_switch_h2);

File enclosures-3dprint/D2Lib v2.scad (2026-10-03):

// Function library
// Parameter names: x,y,z, w=width X, l=length Y, h=height Z, d=diameter

// extra margain for preview
q = .1;
q2 = q*2;


// Draw solid block with certain offset and width,length and height
//   beam(x=,y=,z=,w=,l=,h=);
module beam_wlh(x,y,z,w,l,h) { translate([x,y,z]) cube([w,l,h]); }

// Draw solid block with start and end coordinates
module beam_xyz(x1,x2,y1,y2,z1,z2) { translate([x1,y1,z1]) cube([x2-x1,y2-y1,z2-z1]); }

module beam_xyz_slopedz(x1,x2,y1,y2,z1,z2,slope)
{
    CubePoints = [
      [ x1,  y1,  z1 ],  //0
      [ x2,  y1,  z1 ],  //1
      [ x2,  y2,  z1 ],  //2
      [ x1,  y2,  z1 ],  //3
      [ x1 + slope,  y1 + slope,  z2 ],  //4
      [ x2 - slope,  y1 + slope,  z2 ],  //5
      [ x2 - slope,  y2 - slope,  z2 ],  //6
      [ x1 + slope,  y2 - slope,  z2 ]]; //7
      
    CubeFaces = [
      [0,1,2,3],  // bottom
      [4,5,1,0],  // front
      [7,6,5,4],  // top
      [5,6,2,1],  // right
      [6,7,3,2],  // back
      [7,4,0,3]]; // left
      
    polyhedron( CubePoints, CubeFaces );   
}

module beam_xyz_slopedz4(x1,x2,y1,y2,z1,z2,slope1,slope2,slope3,slope4)
{
    CubePoints = [
      [ x1,  y1,  z1 ],  //0
      [ x2,  y1,  z1 ],  //1
      [ x2,  y2,  z1 ],  //2
      [ x1,  y2,  z1 ],  //3
      [ x1 + slope1,  y1 + slope3,  z2 ],  //4
      [ x2 - slope2,  y1 + slope3,  z2 ],  //5
      [ x2 - slope2,  y2 - slope4,  z2 ],  //6
      [ x1 + slope1,  y2 - slope4,  z2 ]]; //7
      
    CubeFaces = [
      [0,1,2,3],  // bottom
      [4,5,1,0],  // front
      [7,6,5,4],  // top
      [5,6,2,1],  // right
      [6,7,3,2],  // back
      [7,4,0,3]]; // left
      
    polyhedron( CubePoints, CubeFaces );   
}

module beam_xy_sloped(x,y,z,w,l,h,slope) { translate([0,0,z]) linear_extrude(height=h) polygon([[x+slope,y],[x+w-slope,y],[x+w,y+slope],[x+w,y+l-slope],[x+w-slope,y+l],[x+slope,y+l],[x,y+l-slope],[x,y+slope]]); }

module beam_xy_rounded(x,y,z,w,l,h,r)
{
   union()
   {
      beam_xy_sloped(x=x,y=y,z=z,w=w,l=l,h=h,slope=r);
      cylinder_z(x=x+r,y=y+r,z=z,d=r*2,h=h);
      cylinder_z(x=x+w-r,y=y+r,z=z,d=r*2,h=h);
      cylinder_z(x=x+r,y=y+l-r,z=z,d=r*2,h=h);
      cylinder_z(x=x+w-r,y=y+l-r,z=z,d=r*2,h=h);
   }
}

module sloped_beamxy(x,y,z,w,l,h,slope) { translate([0,0,z]) linear_extrude(height=h) polygon([[x+slope,y],[x+w-slope,y],[x+w,y+slope],[x+w,y+l-slope],[x+w-slope,y+l],[x+slope,y+l],[x,y+l-slope],[x,y+slope]]); }

// Draw cilinder with height in x-axis (y,z=center position)
module cylinder_x(x,y,z,d,h) { translate([x,y,z]) rotate([0,90,0]) cylinder(h=h,d=d); }

// Draw cilinder with height in y-axis (x,z=center position)
module cylinder_y(x,y,z,d,h) { translate([x,y,z]) rotate([-90,0,0]) cylinder(h=h,d=d); }

// Draw cilinder with height in z-axis (x,y=center position)
module cylinder_z(x,y,z,d,h) { translate([x,y,z]) cylinder(h=h,d=d); }

// Draw cilinder with height in z-axis (x,y=center position)
module tube_z(x,y,z,innerd,outerd,h) { translate([x,y,z]) difference() { cylinder(h=h,d=outerd); cylinder(h=h,d=innerd); } }

// Draw cone with height in x-axis (y,z=center position)
module cone_x(x,y,z,h,d1,d2) { translate([x,y,z]) rotate([0,90,0]) cylinder(h=h,d1=d1,d2=d2); }

// Draw cone with height in y-axis (x,z=center position)
module cone_y(x,y,z,h,d1,d2) { translate([x,y,z]) rotate([-90,0,0]) cylinder(h=h,d1=d1,d2=d2); }

// Draw cone with height in z-axis (x,y=center position)
module cone_z(x,y,z,h,d1,d2) { translate([x,y,z]) cylinder(h=h,d1=d1,d2=d2); }

// Draw donut in the xy plane (x,y=center position)
module donut_xy(x,y,z,innerd,outerd) { translate([x,y,z]) rotate_extrude() translate([(innerd+outerd) / 4, 0, 0]) circle(r = (outerd-innerd)/4); }

// Draw pie in the xy plane (a1,a2 = from,to angle)
module pie_xy(x,y,z,d,h,a1,a2) { translate([x,y,z]) rotate([0,0,a1]) rotate_extrude(angle=a2-a1) square([d/2,h]); }

module elliptic_sphere(x1,x2,y1,y2,z1,z2)
{
    translate([x1,y1,z1])
        scale([x2-x1,y2-y1,z2-z1])
            translate([.5,.5,.5])
                sphere(.5);
}

module polyhedron_xy(x1,y1,x2,y2,x3,y3,x4,y4,z1,x5,y5,x6,y6,x7,y7,x8,y8,z2)
{
    CubePoints = [
      [  x1,  y1,  z1 ],  //0
      [  x2,  y2,  z1 ],  //1
      [  x3,  y3,  z1 ],  //2
      [  x4,  y4,  z1 ],  //3
      [  x5,  y5,  z2 ],  //4
      [  x6,  y6,  z2 ],  //5
      [  x7,  y7,  z2 ],  //6
      [  x8,  y8,  z2 ]]; //7
      
    CubeFaces = [
      [0,1,2,3],  // bottom
      [4,5,1,0],  // front
      [7,6,5,4],  // top
      [5,6,2,1],  // right
      [6,7,3,2],  // back
      [7,4,0,3]]; // left
      
    polyhedron( CubePoints, CubeFaces );    
}


module polyhedron_xyz(x1,y1,z1,x2,y2,z2,x3,y3,z3,x4,y4,z4,x5,y5,z5,x6,y6,z6,x7,y7,z7,x8,y8,z8)
{
    CubePoints = [
      [  x1,  y1,  z1 ],  //0
      [  x2,  y2,  z2 ],  //1
      [  x3,  y3,  z3 ],  //2
      [  x4,  y4,  z4 ],  //3
      [  x5,  y5,  z5 ],  //4
      [  x6,  y6,  z6 ],  //5
      [  x7,  y7,  z7 ],  //6
      [  x8,  y8,  z8 ]]; //7
      
    CubeFaces = [
      [0,1,2,3],  // bottom
      [4,5,1,0],  // front
      [7,6,5,4],  // top
      [5,6,2,1],  // right
      [6,7,3,2],  // back
      [7,4,0,3]]; // left
      
    polyhedron( CubePoints, CubeFaces );    
}

//Transforms a two dimmensional object in the XY plane to a spiral extrusion with a cross section perpendicular to the extrusion of the original two dimmensional object.
// Radius is the inital radius of the spiral.
// EndRadius is the final radius of the spiral. If not specified, it is the same as Radius.
// Spiral proceeds counter clockwise from start radius to end radius.
// Pitch is the change in Z per revolution of the spiral (this can be negative) unless Height is zero, in which case Pitch is the change in Radius/revolution.
// Starts is the number of spirals.
// Height is the total height of the spiral (this should be positive), can be zero. If pitch is positive, height goes up, if pitch is negative, height goes down
// StepsPerRev is the number of linear extruded segments per revolution of the spiral. A larger number generates a smoother spiral

    //Wraper function for backwords compatibility.
module spiral_extrude(Radius=1,EndRadius=-1,Pitch=50,Starts=1,Height=1,StepsPerRev=50){
    Angle=abs((Height!=0)?360*Height/Pitch:360*(Radius-EndRadius)/Pitch);
    ZPitch=(Height!=0)?Pitch:0;
    RPitch=(Height!=0)?((EndRadius!=-1)?(EndRadius-Radius)/abs(Height/Pitch):0):Pitch;
    
    extrude_spiral(StartRadius=Radius, Angle=Angle, ZPitch=ZPitch, RPitch=RPitch, StepsPerRev=StepsPerRev,Starts=Starts)children();
}


    // Start radius is the radius at which the extrude will start.
    // Angle is the number of degrees of rotation of the extrusion. This is always counter clock wise about the z axis.
    // ZPitch is the change in height per revolution, can be negative.
    // RPitch is the change in radius per revolution, can be negative.
    // StepsPerRev is the number of segments that will be drawn per revolution. Note that the last segment can be a partial segment.
    // Starts is the number of equally spaced copies of the spiral that will be drawn.
module extrude_spiral(StartRadius=10,Angle=360,ZPitch=0,RPitch=0,StepsPerRev=50,Starts=1){
    NumberOfSteps=ceil(Angle/360*StepsPerRev)-1;
        //Number of degrees of last step to use.
    Remainder=((Angle/360*StepsPerRev)-floor(Angle/360*StepsPerRev));
    for(i=[0:NumberOfSteps]){
        for(j=[0:Starts-1]){
            rotate([0,0,360*i/StepsPerRev+360*j/Starts]){
                    //Current Radius
                LocRadius=StartRadius+i*RPitch/StepsPerRev;
                    //Radius at next junction
                LocRadiusJoint=LocRadius/cos(360/(2*StepsPerRev))-RPitch*360/StepsPerRev/2;
                    //Length of line connecting endpoints of the current radius and the radius of the next joint
                TaperLen=sqrt(pow(LocRadius,2)+pow(LocRadiusJoint,2)-2*LocRadius*LocRadiusJoint*cos(360/(2*StepsPerRev)));
                    //Angle of above line relative to the current radius
                TaperAngle=90-asin(max(min(sin(360/(2*StepsPerRev))*LocRadiusJoint/TaperLen,1),-1));
 
                translate([LocRadius,0,i*ZPitch/StepsPerRev]){
                    segment(Radius=LocRadius, ZPitch=ZPitch, StepsPerRev=StepsPerRev, First=i==0, Last=(i==NumberOfSteps)?Remainder:0,RPitch=RPitch)children();
                }
            }
        }
    }
}
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

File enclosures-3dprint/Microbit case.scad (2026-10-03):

use <D2Lib v2.scad>;

// Dimensions in mm
// Ender3 v2: x=224, y=212
// battery box: 15.5 x 25.8 x 52.75 conn: 5.6 x 4.2
// microbit: 43.2 x 11 x 51.8
// cable: 60 x 7.2 x 66     16.4x7.2   10x6.2
//
// L: 1.2 + 3x (44.2 + .6 + 26.8) + .6 + 1.2 - .6 = 218.4
// W: 1.2 + 9x (7.2 + .6 + 15.5) + .6 + 1.2 - .6 = 216.9

inner_height = 50;
outer_wall = 1.2;
inner_wall = 0.6;
bottom = 1;
battery_l = 26.8;
battery_w = 16;
connb_w = 6.5;
connb_l = 6.5;
usbm_w = 7;
usbm_l = 15;
usba_w = 10;
usba_l = 17.4;
microbit_l = 44.2;

count_w = 9;
count_l = 3;

inner_width = usbm_w + inner_wall + battery_w;
inner_length = microbit_l + inner_wall + battery_l;


// Init
$fn=$preview ? 20 : 50;
q = .01;
q2 = q*2;

total_inner_width = (inner_width + inner_wall) * count_w - inner_wall;
total_inner_length = (inner_length + inner_wall) * count_l - inner_wall;

echo("Total x: ", total_inner_width + outer_wall * 2);
echo("Total y: ", total_inner_length + outer_wall * 2);

// bottom
beam_xyz(0, total_inner_width + outer_wall * 2, 0, total_inner_length + outer_wall * 2, 0, bottom);

// outer wall
beam_xyz(0,total_inner_width + outer_wall * 2, 0, outer_wall, bottom, inner_height + bottom);
beam_xyz(0,total_inner_width + outer_wall * 2, total_inner_length + outer_wall, total_inner_length + outer_wall * 2, bottom, inner_height + bottom);
beam_xyz(0, outer_wall, 0, total_inner_length + outer_wall * 2, bottom, inner_height + bottom);
beam_xyz(total_inner_width + outer_wall, total_inner_width + outer_wall * 2, 0, total_inner_length + outer_wall * 2, bottom, inner_height + bottom);

// inner walls
for (x = [1:count_w-1])
    beam_xyz(outer_wall + x * (inner_width + inner_wall) - inner_wall, outer_wall + x * (inner_width + inner_wall), outer_wall, total_inner_length + outer_wall, bottom, inner_height + bottom);

for (y = [1:count_l-1])
    beam_xyz(outer_wall,outer_wall + total_inner_width, outer_wall + y * (inner_length + inner_wall) - inner_wall, outer_wall + y * (inner_length + inner_wall), bottom, inner_height + bottom);

// inner compartiments
for (x = [0:count_w-1])
    for (y = [0:count_l-1])
        translate([x * (inner_width + inner_wall) + outer_wall, y * (inner_length + inner_wall) + outer_wall, bottom])
            innerWalls();

module innerWallsV1()
{
    // h walls
    beam_xyz(0,inner_width, microbit_l, microbit_l + inner_wall, 0, inner_height);
    beam_xyz(0,usba_w, usba_l, usba_l + inner_wall, 0, inner_height);
    beam_xyz(0,usba_w, microbit_l - usba_w - inner_wall, microbit_l - usba_w, 0, inner_height);
    beam_xyz(0,usbm_w, microbit_l + inner_wall + usbm_w, microbit_l + inner_wall + usbm_w + inner_wall, 0, inner_height);
    beam_xyz(0,usbm_w, inner_length - usbm_l - inner_wall, inner_length - usbm_l, 0, inner_height);
    
    // v walls
    beam_xyz(usba_w, usba_w + inner_wall, 0, microbit_l, 0, inner_height);
    beam_xyz(usbm_w, usbm_w + inner_wall, microbit_l + inner_wall, inner_length, 0, inner_height);
}


module innerWalls()
{
    // h walls
    beam_xyz(0,inner_width, microbit_l, microbit_l + inner_wall, 0, inner_height);
    beam_xyz(0,usba_w, usba_l, usba_l + inner_wall, 0, inner_height);
    beam_xyz(usba_w + inner_wall, usba_w + inner_wall + connb_w + inner_wall, connb_l, connb_l + inner_wall, 0, inner_height);
    beam_xyz(0,usbm_w, inner_length - usbm_l - inner_wall, inner_length - usbm_l, 0, inner_height);
    
    // v walls
    beam_xyz(usba_w, usba_w + inner_wall, 0, microbit_l, 0, inner_height);
    beam_xyz(usbm_w, usbm_w + inner_wall, microbit_l + inner_wall, inner_length, 0, inner_height);
    beam_xyz(usba_w + inner_wall + connb_w, usba_w + inner_wall + connb_w + inner_wall, 0, connb_l + inner_wall, 0, inner_height);
}

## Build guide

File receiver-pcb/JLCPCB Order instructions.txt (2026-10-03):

- Create 1 zip file from the Gerber-JLCPCB folder
- Upload this zip to jlcpcb.com (choose Add gerber file)
- Select your Quantity (the more the cheaper per board)
- Change PCB Color to Black
- Change Surface Finish to LeadFree HASL (If ROHS is required in your country, always the case for the EU)
- Choose Mark on PCB: Remove Mark
All other options are oke by default

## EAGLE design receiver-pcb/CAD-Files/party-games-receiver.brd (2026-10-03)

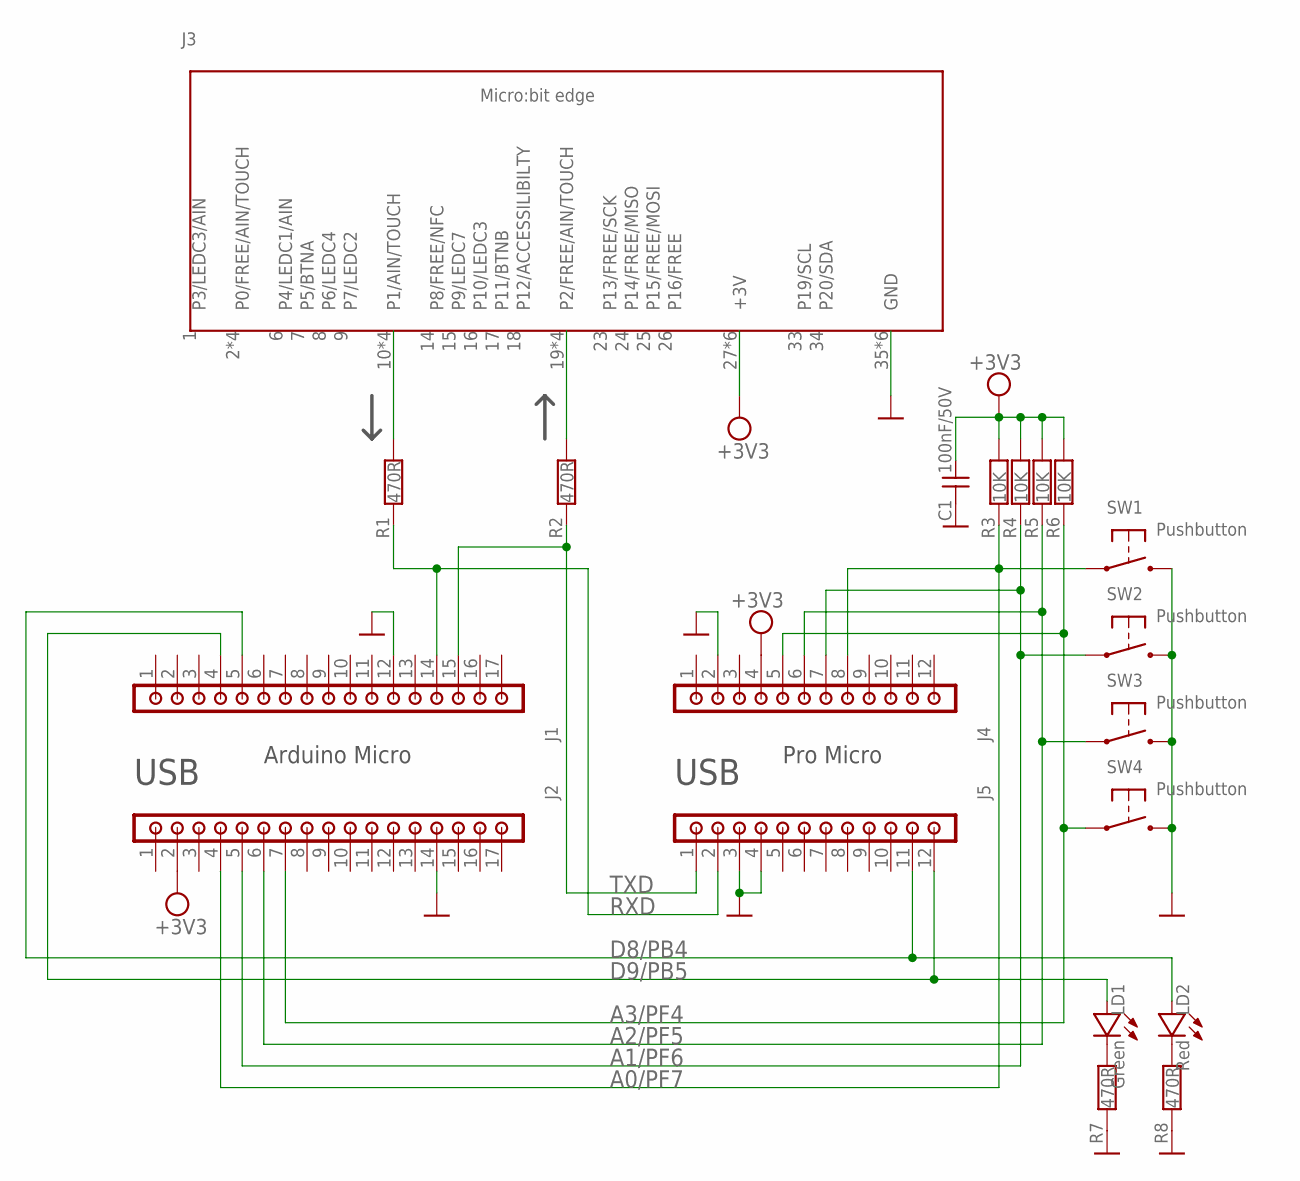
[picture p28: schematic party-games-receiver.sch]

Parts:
C1: CC100NA; CAP_0805
J1, J2: CJHDR1X17MA; CON_HDR_M_1X17
J3: CJMBITH; SOCKET_MBIT_H
J4, J5: CJHDR1X12MA; CON_HDR_M_1X12
LD1: CDLEDGNC; LED_0805
LD2: CDLEDRDC; LED_0805
R1, R2, R7, R8: CR470RA; RES_0805
R3, R4, R5, R6: CR10KA; RES_0805
SW1, SW2, SW3, SW4: CSWPUSHA; SWITCH_PUSH_5MM

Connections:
+3V3: C1.2, J2.2, J3.27 (+3V), J3.28 (+3V), J3.29 (+3V), J3.30 (+3V), J3.31 (+3V), J3.32 (+3V), J4.4, R3.2, R4.2, R5.2, R6.2
A0/PF7: J2.4, J4.8, R3.1, SW1.3, SW1.4
A1/PF6: J2.5, J4.7, R4.1, SW2.3, SW2.4
A2/PF5: J2.6, J4.6, R5.1, SW3.3, SW3.4
A3/PF4: J2.7, J4.5, R6.1, SW4.3, SW4.4
D8/PB4: J1.5, J5.11, LD2.A
D9/PB5: J1.4, J5.12, LD1.A
GND: C1.1, J1.12, J2.14, J3.35 (GND), J3.36 (GND), J3.37 (GND), J3.38 (GND), J3.39 (GND), J3.40 (GND), J4.2, J5.3, J5.4, R7.1, R8.1, SW1.1 (S), SW1.2 (S), SW2.1 (S), SW2.2 (S), SW3.1 (S), SW3.2 (S), SW4.1 (S), SW4.2 (S)
unnamed: LD1.C, R7.2
unnamed: J3.10 (P1/AIN/TOUCH), J3.11 (P1/AIN/TOUCH), J3.12 (P1/AIN/TOUCH), J3.13 (P1/AIN/TOUCH), R1.2
unnamed: J3.19 (P2/FREE/AIN/TOUCH), J3.20 (P2/FREE/AIN/TOUCH), J3.21 (P2/FREE/AIN/TOUCH), J3.22 (P2/FREE/AIN/TOUCH), R2.2
unnamed: LD2.C, R8.2
RXD: J1.14, J5.2, R1.1
TXD: J1.15, J5.1, R2.1

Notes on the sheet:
USB
Arduino Micro
Pro Micro

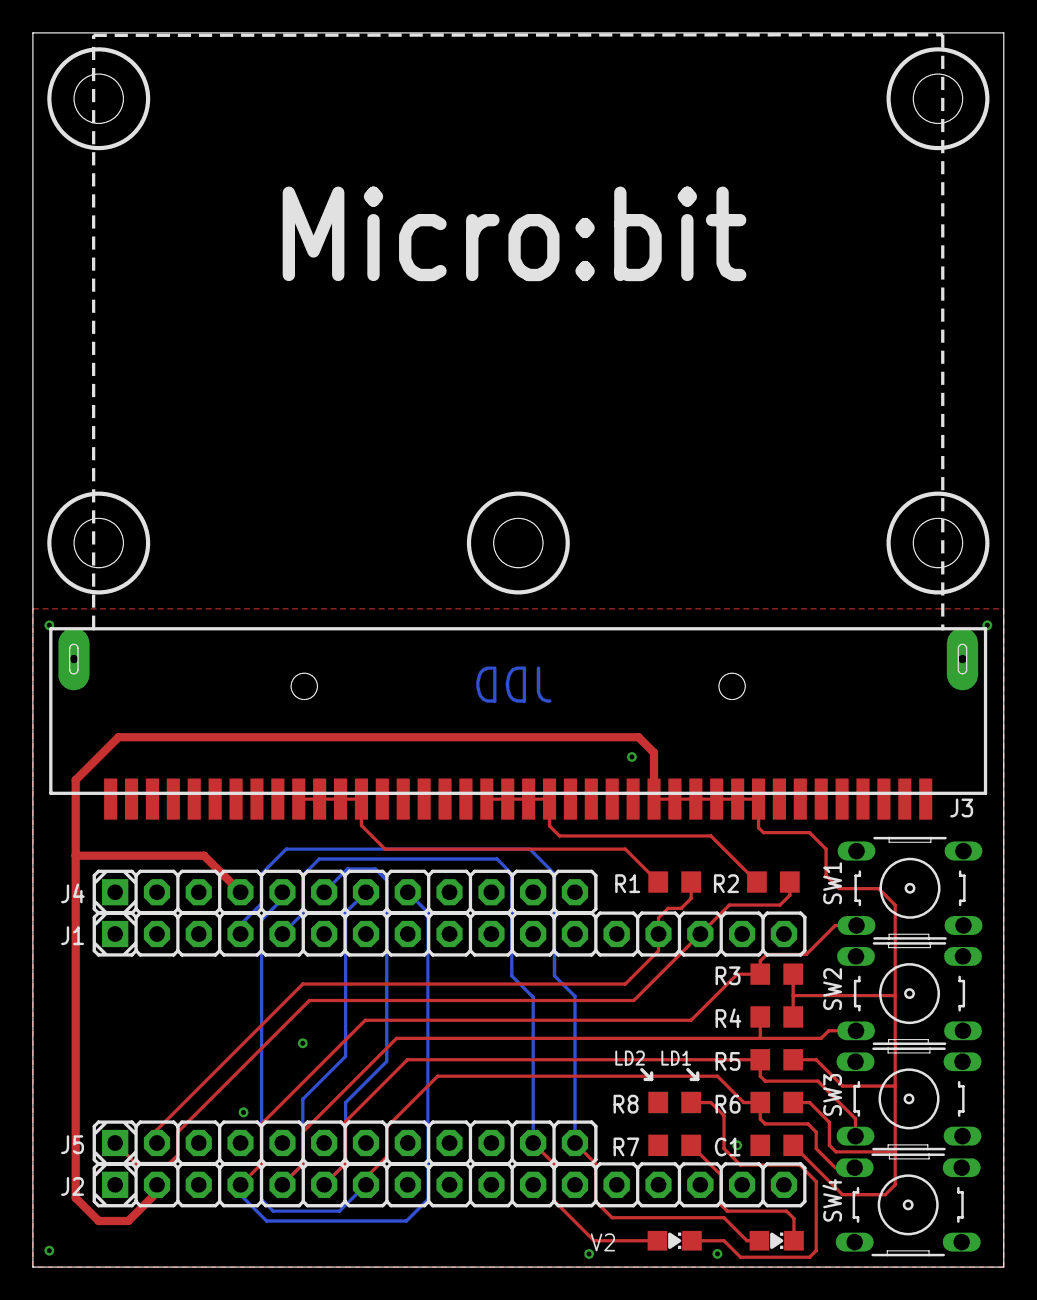
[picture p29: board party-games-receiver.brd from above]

Board: 2 copper layers, 59.0 x 75.0 mm, 25 parts (0 on the bottom side), 14 nets.

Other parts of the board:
U$5, U$6, U$7, U$8, U$9: HOLE_3MM_ISOLATED

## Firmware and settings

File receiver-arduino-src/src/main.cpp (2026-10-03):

// Settings
#define DEBUG 0                  // 1 = less logging to not affect performance, 2 = extra logging for every key, less performance, 3 = even more
#define PLAYER_CHEAT_DELAY_MS 60 // when the same key is received within this delay, don't send repeated key as long as subsequent keys are below this delay (prevent spamming, cheating and backlog floods)
#define KEYPRESS_MAX_TIME_MS 50  // nominal time between the keydown-keyup event. Must be smaller than PLAYER_DELAY_MS to allow time between keyup and the next keydown.
#define KEYPRESS_MIN_TIME_MS 20  // when MAX_KEYS_SAME_TIME is reached, the keypress time can be shortened to make place for the new key. New key presses are discarded (KEYPRESS_BUFFER 0) or delayed (KEYPRESS_BUFFER 1) to ensure KEYPRESS_MIN_TIME_MS
#define KEYPRESS_BUFFER 1        // 1 = do not discard new keypresses when the max capacity for MAX_KEYS_SAME_TIME is reached but send delayed. Important to keep games like flappy bird running when everyone presses at about the same time
#define KEYPRESS_DELAY_MS 1      // 1 = wait at least this time between sending keys to host
#define SAME_KEY_DELAY_MS 40     // wait at least this time between sending the same key to host (scratch will miss the key if pressed within 32ms)
#define MAX_KEYS_SAME_TIME 6     // maximum keys pressed at the same time (USB Limit). Max rate = 1000 * MAX_KEYS_SAME_TIME / KEYPRESS_MIN_TIME_MS keys/sec
#define MULTI_BUTTON_MODE_DEFAULT false    // multiple buttons per player support when letters are prefixed with 0..9, with only 1ms keydown/keyup. For specific scratch multiplayer game purpose (allow 11 keys per player: a 0a 1a 2a 3a 4a 1b 2b 3b)....
#define KEY_DOWN_UP_EVENT_MODE true // + and - prefixes send separate keydown/keyup events instead of combined keypress. numbers prefixed with + - also are send as numbers even if multibuttonmode key is anabled
#define KEY_DOWN_UP_MAX_TIME_MS 10000  // if no keyup is received, release key after this time
#define KB_LAYOUT1 KeyboardLayout_fr_FR_numpad
#define KB_LAYOUT2 KeyboardLayout_en_US_numpad
#define LONG_PRESS_TIME 500
#define FROM_KEY 26              // 26=enter, 27=esc, 28=up, 29=down, 30=left, 31=right, 32=space, ...
#define TILL_KEY_EXCL 128
#define KEY_DOWN_PREFIX '\x0E'
#define KEY_UP_PREFIX '\x0F'

// LED's and buttons on interface circuit board
#define LED_RED 8   // atmel PB4  Indicates when paused (supress keystrokes)
#define LED_GREEN 9 // atmel PB5  Show receiving data
#define BUTTON1 18  // atmel PF7  Send single char 'a' to keyboard (to test qwerty / azerty)
#define BUTTON2 19  // atmel PF6  Send 30 keys/sec a..z (2x each)
#define BUTTON3 20  // atmel PF5  Send 300 keys/sec a..z (20x each)
#define BUTTON4 21  // atmel PF4  Pause / Resume

// Includes
#include <Arduino.h>
#include <Keyboard.h>
#include <CustomKeyboardLayouts.h>

// Global Variables
bool First = true;
bool Paused = false;
bool MultiButtonMode = MULTI_BUTTON_MODE_DEFAULT;
signed char FastNumPrefix = -1;     // for MultiButtonMode=true: number received to send with next character with only 1ms down/up delay
signed char KeyUpDownPrefix = -1; // current received + or - prefix when KEY_DOWN_UP_EVENT_MODE == true
unsigned long LastKbSendTimeMs = 0;   // last millis() a char press or release was sent to the keyboard, to wait for the next millisecond (send max 1000 events / sec)
unsigned long LastRedLedOnTimeMs = 0; // last millis() the red led was turned on, for off delay
unsigned long LastSerialReceiveTimeMs = 0; // last millis() a char was received from serial
unsigned long LastKbSendTimePerKey[TILL_KEY_EXCL - FROM_KEY]; // last time when this key was sent to the computer
unsigned long LastSerialReceiveTimePerKey[TILL_KEY_EXCL - FROM_KEY]; // last time when this key was received from serial (excluding number prefixed keys when SPECIAL_NUMBER_MODE)
unsigned char KeyState[TILL_KEY_EXCL - FROM_KEY]; // 0=not pressed, 1=pressed, 2=pressed&hold
unsigned char NrKeysDown = 0;
unsigned char SimulateButton = 0;
unsigned char CurrentKbLayout = 1;

signed char DelayedFastNumKeys[TILL_KEY_EXCL - FROM_KEY]; // buffer for prefixed num keys as numbers can easily exceed SAME_KEY_DELAY_MS they are send later
unsigned char ScanBufferIndex;

#if DEBUG > 0
    // only 2kb ram, save space for non debug to have more stack space
    unsigned long NrSendPerKey[TILL_KEY_EXCL - FROM_KEY]; // times a character was sent to the kb
    unsigned long NrSupressedPerKey[TILL_KEY_EXCL - FROM_KEY]; // times a character was supressed

    unsigned long ShortestKeypress; // for debug
    unsigned char MaxKeysDown; // for debug
#endif

#if KEYPRESS_MIN_TIME_MS > KEYPRESS_MAX_TIME_MS
    #error Illegal values
#endif

#if DEBUG > 0
    #warning Debug mode. Avoid using this in real time
#endif

template <class T> void LogNumber(T value, unsigned char digits = 0, char multiplier = 0)
{
    unsigned char revbuf[10];
    unsigned char ctr = 0;

    // avoid printing 0000
    if (multiplier > 0 && value == 0)
        multiplier = 0;

    // make sure digits at at least 1 larger as #decimals (example 0.000)
    if (digits <= -multiplier)
        digits = 1 - multiplier;

    // store number with minimum nr of digits and at least 1 digit
    while (value || !ctr)
    {
        revbuf[ctr++] = (value % 10) + '0';
        value /= 10;
        if (digits > 0)
          digits--;
    }

    // at this point: digits = remaining leading zeros, ctr = actual digits in buffer
    char decimalPos = ctr + digits + multiplier; // position to write the decimal point (# digits before)

    while (digits--)
    {
        if (decimalPos-- == 0)
            Serial.write('.');

        Serial.write('0');
    }

    while (ctr)
    {
        if (decimalPos-- == 0)
            Serial.write('.');

        Serial.write(revbuf[--ctr]);
    }

    while (decimalPos-- > 0)
        Serial.write('0');
}

void LogNumber(long value, unsigned char digits = 0, char multiplier = 0)
{
    if (value < 0)
    {
        Serial.write('-');
        value = -value;
    }

    LogNumber<unsigned long>(value, digits, multiplier);
}

void LogNumber(unsigned long value, unsigned char digits = 0, char multiplier = 0)
{
    LogNumber<unsigned long>(value, digits, multiplier);
}

void LogPStr(const char* pstr)
{
    while (char c = pgm_read_byte(pstr++))
        Serial.write(c);
}

void LogChar(char c)
{
    Serial.write(c);
}

void SetLedR(bool state)
{
    digitalWrite(LED_RED, state ? 1 : 0);
}

void SetLedG(bool state)
{
    digitalWrite(LED_GREEN, state ? 1 : 0);
}

void BlinckLeds()
{
    for (unsigned char i = 0; i < 10; i++)
    {
        delay(100);
        SetLedR(i % 2 == 0);
        SetLedG(i % 2 == 1);
    }
    
    SetLedR(Paused);
    SetLedG(MultiButtonMode);
}

void ClearTimers()
{
    LastKbSendTimeMs = 0;
    LastSerialReceiveTimeMs = 0;
    LastRedLedOnTimeMs = 0;
    for (unsigned char i = 0; i < (TILL_KEY_EXCL - FROM_KEY); i++)
    {
        LastSerialReceiveTimePerKey[i] = 0;
        LastKbSendTimePerKey[i] = 0;
        DelayedFastNumKeys[i] = -1;

        #if DEBUG > 0
            NrSendPerKey[i] = 0;
            NrSupressedPerKey[i] = 0;
        #endif
    }
    #if DEBUG > 0
        MaxKeysDown = 0;
        ShortestKeypress = KEYPRESS_MAX_TIME_MS;
    #endif
}

void PressKey(char keyChar, bool holdKeyDown = false)
{
    unsigned char charIndex = keyChar - FROM_KEY;

    // check if already pressed
    if (KeyState[charIndex] != 0)
    {
        #if DEBUG >= 1
            LogPStr(PSTR("Error PressKey() Key is already pressed!\r\n"));
        #endif
        return;
    }

    // Inter key delay
    while ((millis() - LastKbSendTimeMs) < KEYPRESS_DELAY_MS)
        ;

    // Same key delay
    while(millis() - LastKbSendTimePerKey[charIndex] < SAME_KEY_DELAY_MS)
        ;

    Keyboard.press(keyChar);
    KeyState[charIndex] = holdKeyDown ? 2 : 1;
    LastKbSendTimeMs = millis();
    LastKbSendTimePerKey[charIndex] = LastKbSendTimeMs; // ReleaseKeys() needs this to release key after KEYPRESS_TIME_MS
    NrKeysDown++;

    #if DEBUG >= 2
        LogChar('+');
        LogChar(keyChar);
    #endif

    #if DEBUG >= 1
        if (NrKeysDown > MaxKeysDown)
            MaxKeysDown = NrKeysDown;

        NrSendPerKey[charIndex]++;

        if (NrKeysDown > MAX_KEYS_SAME_TIME)
            LogPStr(PSTR("Error PressKey() Exceeded MAX_KEYS_SAME_TIME!\r\n"));
    #endif
}

void ReleaseKey(char keyChar)
{
    unsigned char charIndex = keyChar - FROM_KEY;

    // check if pressed
    if (KeyState[charIndex] == 0)
    {
        #if DEBUG >= 1
            LogPStr(PSTR("Error ReleaseKey(): Key is not pressed!\r\n"));
        #endif
        return;
    }

    //while ((millis() - LastKbSendTimeMs) < KEYPRESS_DELAY_MS)
    //    ;

    Keyboard.release(keyChar);
    KeyState[charIndex] = 0;
    //LastKbSendTimeMs = millis();

    #if DEBUG >= 2
        LogChar('-');
        LogChar(keyChar);
    #endif

    if (NrKeysDown > 0)
        NrKeysDown--;
    #if DEBUG >= 1
        else
            LogPStr(PSTR("Error ReleaseKey() NrKeysDown does not match\r\n"));
    #endif
}

// check all keys and release if necessary. If fast is true, allow shorter time than KEYPRESS_MAX_TIME_MS but not shorter than KEYPRESS_MIN_TIME_MS
void ReleaseKeys(bool fast)
{  
    unsigned long currentTime = millis();
    unsigned long longestKey = 0;
    unsigned char longestKeyIndex = 0;

    // activity led off after 20ms
    if (currentTime - LastSerialReceiveTimeMs > 20)
        SetLedG(MultiButtonMode);

    if (currentTime - LastRedLedOnTimeMs > 20)
        SetLedR(Paused);

    for (unsigned char i = 0; i < (TILL_KEY_EXCL - FROM_KEY); i++)
    {
        if (KeyState[i] != 0)
        {
            unsigned long pressTime = currentTime - LastKbSendTimePerKey[i];
            if ((KeyState[i] == 1 && pressTime >= KEYPRESS_MAX_TIME_MS) || pressTime >= KEY_DOWN_UP_MAX_TIME_MS)
            {
                // Release key
                ReleaseKey(i + FROM_KEY);
                return; // continue on the next main loop iteration to increase respond time
            }

            // find the longest pressed key for later use
            if (pressTime > longestKey)
            {
                longestKey = pressTime;
                longestKeyIndex = i;
            }
        }
    }

    if (fast && NrKeysDown >= MAX_KEYS_SAME_TIME && longestKey >= KEYPRESS_MIN_TIME_MS)
    {
        // queue is full, allow to release the longest pressed key
        ReleaseKey(longestKeyIndex + FROM_KEY);

        #if DEBUG > 0
            if (ShortestKeypress > longestKey)
                ShortestKeypress = longestKey;
        #endif
    }
}

bool BufferFastNumNeeded(unsigned char numPrefix, unsigned char keyChar)
{
    unsigned long currentTime = millis();
    unsigned char charIndex = keyChar - FROM_KEY;
    unsigned char prefixCharIndex = '0' + numPrefix - FROM_KEY;

    if ((currentTime - LastKbSendTimePerKey[prefixCharIndex]) < SAME_KEY_DELAY_MS)
        return true; // prefix key is repeated too soon

    if ((currentTime - LastKbSendTimePerKey[charIndex]) < SAME_KEY_DELAY_MS)
        return true; // player key is repeated too soon

    return false;
}

// check if there are fast num keys ready to send and send them. Result: true if buffer is empty
bool ProcessBufferFastNum(unsigned char charIndex)
{
    signed char numPrefix = DelayedFastNumKeys[charIndex];
    if (numPrefix == -1)
        return true;

    unsigned char keyChar = FROM_KEY + charIndex;
    if (BufferFastNumNeeded(numPrefix, keyChar))
        return false; // keys still not pressable within MAX_KEYS_SAME_TIME

    DelayedFastNumKeys[charIndex] = -1; // remove from buffer

    if (Paused)
        return true;

    // key can be pressed, wait for available MAX_KEYS_SAME_TIME
    while (NrKeysDown >= MAX_KEYS_SAME_TIME)
    {
        // maximum keys already pressed. try to release a key earlier
        ReleaseKeys(true);

        if (NrKeysDown >= MAX_KEYS_SAME_TIME)
        {
            // unable to free key
            SetLedR(!Paused); // blink to indicate overflow
            LastRedLedOnTimeMs = millis();

            #if KEYPRESS_BUFFER != 1
                // do not buffer if release failed
                #if DEBUG > 0
                    NrSupressedPerKey[charIndex]++;
                #endif

                #if DEBUG >= 2
                    LogPStr(PSTR("ProcessChar(): Maximum keys pressed, discard key\r\n"));
                #endif

                return true;
            #endif

            // block till key can be released. keep new keypresses in serial buffer
            delay(1);
        }
    }

    // Player key can still be pressed it previous was not num prefixed
    if (KeyState[charIndex] != 0)
        ReleaseKey(keyChar);

    // Send keydown/up prefix
    PressKey('0' + numPrefix);
    ReleaseKey('0' + numPrefix);

    // Send keydown/up event
    PressKey(keyChar);
    ReleaseKey(keyChar);

    return true;
}

bool BufferFastNum(unsigned char numPrefix, unsigned char keyChar)
{
    if (!BufferFastNumNeeded(numPrefix, keyChar))
        return false;

    unsigned char charIndex = keyChar - FROM_KEY;
    DelayedFastNumKeys[charIndex] = numPrefix;

    return true;
}

void ProcessChar(char c)
{
    if (c >= '0' && c <= '9' && KeyUpDownPrefix == -1)
    {
        #if DEBUG >= 1
            if (FastNumPrefix != -1)
                LogPStr(PSTR("ProcessChar(): number prefixed by number. not supported\r\n"));
        #endif

        FastNumPrefix = c - '0';
        return; // number will be processed next time, or not when special number mode is off. For up/down events, send as number
    }
    
    if (KEY_DOWN_UP_EVENT_MODE && (c == KEY_DOWN_PREFIX || c == KEY_UP_PREFIX))
    {
        #if DEBUG >= 1
            if (FastNumPrefix != -1)
                LogPStr(PSTR("ProcessChar(): keydown.up code prefixed by number. not supported\r\n"));
        #endif

        FastNumPrefix = -1;
        KeyUpDownPrefix = c;
        return; // does not send anything as this indicates to send a down/up event for next character
    }
    
    if (FastNumPrefix != -1 && !MultiButtonMode)
    {
        #if DEBUG >= 1
            LogPStr(PSTR("ProcessChar(): Discard number prefixed char, MultiButtonMode inactive\r\n"));
        #endif

        FastNumPrefix = -1;
        return; // discard number-prefixed keys when special number mode is not active
    }

    // Check valid char
    unsigned char charIndex = c - FROM_KEY;
    if (c < FROM_KEY || c >= TILL_KEY_EXCL)
    {
        #if DEBUG >= 1
            LogPStr(PSTR("ProcessChar(): Unsupported char received\r\n"));
        #endif

        return;
    }

    // check if keyup event was requested
    if (KeyUpDownPrefix == KEY_UP_PREFIX)
    {
        ReleaseKey(c); // safe also when it was not pressed
        KeyUpDownPrefix = -1;
        return;
    }

    // Check time between same player key. As an anti-cheat meausure, extend the wait time if the same key is received below a reasonable "minimum human" time.
    unsigned long prevKeyTime = LastSerialReceiveTimePerKey[charIndex];
    LastSerialReceiveTimePerKey[charIndex] = millis(); // set timer, to allow anti cheat check to block all keypresses if interval is too fast

    if ((prevKeyTime + PLAYER_CHEAT_DELAY_MS) > millis() && KeyUpDownPrefix == -1)
    {
        #if DEBUG > 0
            NrSupressedPerKey[charIndex]++;
        #endif

        #if DEBUG >= 2
            LogPStr(PSTR("ProcessChar(): Supressed repeated key (anti cheat)\r\n"));
        #endif

        // discard key and prefix
        FastNumPrefix = -1;
        return;
    }

    // check if fast key needs to be handled later. for example 1a1b1c2d should be re-arranged to 1a2d1b1c as this is faster and avoids waiting for SAME_KEY_DELAY_MS between 1(a) and 1(b)
    if (FastNumPrefix != -1 && KeyUpDownPrefix == -1 && BufferFastNum(FastNumPrefix, c))
    {
        // process key and prefix on a later time
        FastNumPrefix = -1;
        return;
    }

    // Check if player key already pressed. can happen when anti cheat delay is set shorter than KEYPRESS_MIN_TIME_MS
    // In fast num mode, if survived anti cheat check, allow to release key below KEYPRESS_MIN_TIME_MS (as game should be able to handle 1ms keypresses)
    if (KeyState[charIndex] != 0)
    {
        if (FastNumPrefix == -1 && KeyUpDownPrefix == -1 && (millis() - LastKbSendTimePerKey[charIndex]) < KEYPRESS_MIN_TIME_MS)
        {
            #if DEBUG >= 1
                LogPStr(PSTR("ProcessChar(): Key is already pressed, discard\r\n")); // happens with shorter anti cheat delay than KEYPRESS_MIN_TIME_MS. Discard as it is impossible to execute
            #endif

            LastSerialReceiveTimePerKey[charIndex] = prevKeyTime; // restore timer, do not punish player for next anti cheat check
            // discard key and prefix
            //FastNumPrefix = -1; // already the case
            return;
        }

        ReleaseKey(c); // early release key received to allow re-pressing
    }

    // make room for new keydown as there can be only MAX_KEYS_SAME_TIME pressed at the same time
    while (NrKeysDown >= MAX_KEYS_SAME_TIME)
    {
        // maximum keys already pressed. try to release a key earlier
        ReleaseKeys(true);

        if (NrKeysDown >= MAX_KEYS_SAME_TIME)
        {
            // unable to free key
            SetLedR(!Paused); // blink to indicate overflow
            LastRedLedOnTimeMs = millis();

            #if KEYPRESS_BUFFER != 1
                // do not buffer if release failed
                #if DEBUG > 0
                    NrSupressedPerKey[charIndex]++;
                #endif

                #if DEBUG >= 2
                    LogPStr(PSTR("ProcessChar(): Maximum keys pressed, discard key\r\n"));
                #endif

                // discard key and prefix
                FastNumPrefix = -1;
                KeyUpDownPrefix = -1;
                return;
            #endif

            // block till key can be released. keep new keypresses in serial buffer
            delay(1);
        }
    }

    LastSerialReceiveTimeMs = millis();
    SetLedG(!MultiButtonMode);

    if (Paused)
    {
        // discard key and prefix
        FastNumPrefix = -1;
        KeyUpDownPrefix = -1; // keyup will give a warning because it was not down before, but oke...
        return;
    }

    // Send keydown/up prefix
    if (FastNumPrefix != -1)
    {
        PressKey('0' + FastNumPrefix);
        ReleaseKey('0' + FastNumPrefix);
    }

    // Send keydown event
    PressKey(c, KeyUpDownPrefix == KEY_DOWN_PREFIX);
    KeyUpDownPrefix = -1;

    // In MULTI_BUTTON_MODE prefixed keys are only down for a very short time. The game needs to support this be using keypressed events instead of loop polling
    // normal keys without prefix are pressed bewteen KEYPRESS_MIN_TIME_MS and KEYPRESS_MAX_TIME_MS to support simpeler games using a polling loop
    if (FastNumPrefix != -1)
    {
        ReleaseKey(c);    
        FastNumPrefix = -1;
    }
}
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
void loop()
{
    if (First)
    {
        // Startup delay 1 sec
        First = false;
        ScanBufferIndex = 'a' - FROM_KEY;

        // blink leds
        BlinckLeds();

        #if DEBUG >= 1
            LogPStr(PSTR("Microbit game receiver ready!\r\n"));
            LogPStr(PSTR("In DEBUG Mode "));
            Serial.write('0' + DEBUG);
            LogPStr(PSTR(". Using anti-spam delay of "));
            LogNumber(PLAYER_CHEAT_DELAY_MS);
            LogPStr(PSTR("ms and a keypress time between "));
            LogNumber(KEYPRESS_MIN_TIME_MS);
            LogPStr(PSTR("ms and "));
            LogNumber(KEYPRESS_MAX_TIME_MS);
            LogPStr(PSTR("ms.\r\n"));
        #endif
    }

    #if DEBUG >= 1
        // Debug
        if (Serial.available())
        {
        char cmd = Serial.read();
        if (cmd == '?')
        {
            LogPStr(PSTR("\r\nStats (c=clear):\r\n"
                "Shortest keypress: "));
            LogNumber(ShortestKeypress);
            LogPStr(PSTR("ms\r\n"
                "Max keys down: "));
            LogNumber(MaxKeysDown);
            LogPStr(PSTR(" (USB limit=6)\r\n"));

            for (unsigned char i = 0; i < (TILL_KEY_EXCL - FROM_KEY); i++)
            {
                if (LastSerialReceiveTimePerKey[i] == 0)
                    continue;

                LogPStr(PSTR("Key '"));
                Serial.write(i + FROM_KEY);
                LogPStr(PSTR(": Send: "));
                LogNumber(NrSendPerKey[i]);
                LogPStr(PSTR(": Supr: "));
                LogNumber(NrSupressedPerKey[i]);
                LogPStr(PSTR("\r\n"));
            }
            LogPStr(PSTR("------\r\nPress c to clear\r\n"));
            LogPStr(PSTR("Press 1..9 to simulate button\r\n"));
        }
        else if (cmd == 'c')
        {
            ClearTimers();
            LogPStr(PSTR("Stats cleared.\r\n"));
        }
        else if (cmd >= '1' && cmd <= '9')
        {
            SimulateButton = cmd - '0';
            LogPStr(PSTR("Simulating button "));
            LogChar(cmd);
            LogPStr(PSTR(" in 2 seconds..."));
            delay(2000);
            LogPStr(PSTR("GO!\r\n"));
        }
        else
        {
            //delay(100);
            //Keyboard.write(cmd);
        }
        }
    #endif

    if (Serial1.available())
    {
        char c = Serial1.read();

        #if DEBUG >= 3
            LogPStr(PSTR("Rx char "));
            LogNumber(c);
            LogPStr(PSTR(" at "));
            LogNumber(millis());
            LogPStr(PSTR(" ms.\r\n"));
        #endif

        ProcessChar(c);
    }

    ReleaseKeys(false); //check all keys and release if necessary
    ProcessButtons();
    ProcessBufferFastNum(ScanBufferIndex);

    if (++ScanBufferIndex > 'z' - FROM_KEY)
        ScanBufferIndex = 'a' - FROM_KEY;    
}
